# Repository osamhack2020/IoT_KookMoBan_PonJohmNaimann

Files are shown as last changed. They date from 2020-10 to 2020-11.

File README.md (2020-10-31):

# 국방모바일반납 (Pon Johm Naimann-IoT 파트)





## Introduction
<p align="center">
GitHub contributors
</p>

**국방모바일보안**은 병사와 통제간부 모두가 만족하며 사용할 수 있는, **일방적인 금지와 통제**로 이루어지지 않는 스마트폰 반납 시스템을 개발하기 위한 프로젝트입니다. IoT, APP, WEB 분야의 기술을 함께 사용합니다.

## Manual
본 프로젝트는 오픈소스 프로젝트로 진행되며, 본 프로젝트에 관심이 있는 개발자와 사용자를 위하여 **튜토리얼 GitBook**을 제작하여 공개하고 있습니다.

<p align="center">
<a href="https://kookmoban.gitbook.io/osam/">

</a>
</p>

## Contribution
금년도 오픈소스아카데미 집체교육이 **비대면**으로 이루어짐에 따라, 모든 프로젝트는 **서로 얼굴도 알지 못하는 상태**에서 진행됩니다. 따라서 소통은 실시간 소통이 가능하고 문서화에 유리한 아래의 **Notion 페이지**에서 이루어집니다.

<p align="center">
<a href="https://www.notion.so/OSAM-265735b9b76b4bccbff7ce2c4739acd9"  target="_blank">

</a>
</p>

## License
라이센스의 구체적인 내용 및 써드파티 SW에 대해서는 본 리포지토리의 LICENSE 파일 및 튜토리얼 GitBook의 <a href="https://kookmoban.gitbook.io/osam/license/iot-license">LICENSE 페이지</a>를 참조하십시오.
* IoT
  * Code for Arduino: GPL v3
  * Code for RaspberryPi: BSD 3-Clause
* APP: BSD 3-Clause
* WEB: BSD 3-Clause

## Copyright
Copyrightⓒ 2020 Pon Johm Naimann, All rights reserved.

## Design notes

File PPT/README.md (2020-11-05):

# PPT
* [발표자료 (PDF)](https://github.com/osamhack2020/IoT_KookMoBan_PonJohmNaimann/blob/master/PPT/showdown.pdf)
* [발표자료 (PPTX)](https://github.com/osamhack2020/IoT_KookMoBan_PonJohmNaimann/blob/master/PPT/showdown.pptx)
* [발표자료 (PPSX)](https://github.com/osamhack2020/IoT_KookMoBan_PonJohmNaimann/blob/master/PPT/showdown.ppsx)
* [대본](https://github.com/osamhack2020/IoT_KookMoBan_PonJohmNaimann/blob/master/PPT/script.docx)

# 시연 영상
* [종합시연영상](https://youtu.be/DbWCQ2gI8T8)
* [기기등록영상](https://youtu.be/X1ljW4mC4LE)
* [기기반납영상](https://youtu.be/j-UtmO9tqu4)
* [TOTP시연영상](https://youtu.be/JxOJ6xShL1s)

> 시연영상이 전부 100MB을 넘겨서 직접 첨부가 불가능합니다ㅠㅠ 링크를 참조해주세요!  
> Every performance video exceeds 100MB, so Github rejects to upload these files :( Plz check links above.

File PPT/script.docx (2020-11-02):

안녕하세요, 스마트폰 비대면 반납 시스템을 주제로 ‘국방모바일반납‘ 프로젝트를 진행한 ‘폰 좀 내이만’ 팀입니다. 저희 발표는 다음과 같은 순서로 진행되겠습니다.

혹시 여러분은 이 앱을 아시나요? (청중의 반응을 잠시 듣는다.) 아무래도 군과 관련된 분들은 알고 계신 눈치이고, 그렇지 않은 분들은 잘 모르는 눈치네요. 이 ‘국방모바일보안’이라는 앱은, 군부대 내부에서 카메라 사용을 제한하기 위해 병사들의 스마트폰에 설치하도록 되어있는 앱입니다. 이 앱을 깔면 그 핸드폰에서는 카메라와 관련된 기능에 전혀 접근할 수 없게 됩니다. 카메라를 사용하려고 하면 앱을 강제로 종료하는 식으로 말이죠. 사소한 정보 하나하나가 보안과 직결되는 군에서 꼭 필요한 기능이라고 할 수 있겠죠?

하지만, 이 앱에 대한 평가는 그리 좋지 않습니다. 우선 휴가를 나와서 카메라 제한을 해제했는데도 카메라가 켜지지 않거나, 앱을 설치한 뒤 성능이 저하되고 발열이 심해지거나, 카메라 기능과는 무관한 어플을 강제 종료하는 실질적인 문제가 있습니다. 그리고 앱을 임의로 삭제하는 것을 방지하기 위해 ‘모든 데이터 삭제’ 권한을 요구하는데, 일반 사용자가 보면 걱정부터 들죠. 게다가 아이폰 최신 기종의 경우, 이 어플이 작동하지 않습니다. 이런 불편과 불안을 저희가 직접 경험하고 있던 중에…

이번 온라인 해커톤의 지정과제가 발표되었습니다. 그리고 저희는 이 주제에 주목했는데요, 바로 ‘생활관 병사 스마트폰 비대면 반납 앱’입니다. 저희는 걱정이 들었습니다. 제 2의 ‘국방모바일보안’을 염두에 두고 있는 것은 아닌지 말이죠. 정말 앱을 통해서만 사용자의 동작을 감지하고, 강제성을 동원해서 통제해야만 하는 것인지 생각하던 중에, 어? 이거 IoT를 같이 사용하면 잘 해결할 수 있을 것 같은데? 하고 생각하게 되었습니다.

그래서 저희는 비대면 반납 ‘시스템’을 만들기로 했습니다. 그리고 몇 가지 조건을 걸었어요. 첫째로, 모든 반납과 불출 과정, 반납 현황을 확인하고, 실물을 확인하는 과정까지도 비대면이어야 합니다. 둘째로, 앱에서 많은 권한을 요구해서 스마트폰의 성능과 기능에 영향을 끼치면 안됩니다. 셋째로, 비정상 반납 행위로부터 충분한 방어력을 갖추어야 합니다. 몰래 반입한 스마트폰을 대신 제출하는 등의 행위로부터 말이죠. 마지막으로, 스마트폰의 기종에 무관하게 시스템이 적용될 수 있어야 합니다.

이 조건을 바탕으로 수많은 시스템을 고민하고 검증해보았습니다. 시나리오를 작성하고, 파훼법이 있는지 확인하고, 다시 고민하고. 그 결과 이런 와이어프레임을 만들 수 있었어요. 서버가 난수를 전송하고, 앱에서 QR코드를 띄우고, 이걸 반납기가 읽어서 검증하고. 추가적으로 무게도 재고 사진도 찍어서 기존의 기록과 비교하도록 하면 완벽하겠죠.

하지만 몇 가지 문제가 있었습니다. 첫째로, 사용자가 QR코드를 베끼면 어떡하죠? 스크린샷을 찍어서 다른 기기에 전송하고 대신 반납하면? 아니면 모눈종이에 QR코드를 베끼고 쇳덩이에 붙여서 반납하면? 피식 웃으시는 분들이 계신데, 우리 뛰어난 국군 병사들, 이정도는 충분히 해냅니다.

그래서 대책을 세웠습니다. 기기가 반납기에 들어가고 문이 잠긴 뒤에 앱에 난수를 알려주는 겁니다. 음, 괜찮은 것 같아요.

하지만 또 문제가 생깁니다. 몇몇 부대나 파견지는 네트워크 상황이 좋지 않은 경우도 있거든요. 그래서 또 고민과 조사를 계속한 끝에, TOTP기술을 사용하기로 했습니다. 앱을 초기 등록할 때에만 서버와 통신하여 UUID를 정하고 이후 반납시에는 UUID를 SEED로 하여 TOTP를 생성하는 방식인거죠. 그리고 TOTP생성의 간격을 10초로 두고, 반납기가 기기 진입 후 10초를 기다리게 하면 사용자가 접근하지 못한 깨끗한 QR코드를 인식할 수 있게 됩니다.

이러한 발전 과정을 통해 처음의 시스템은 이렇게 바뀌었습니다. 이 시스템은 반납 과정도 비대면이고, 반납 정보도 서버가 다 저장하고 있으므로 현황 확인도 비대면으로 할 수 있습니다. 게다가 앱에서 요구하는 권한은 일절 없으면서, 기종과 무관하게 구현 가능합니다. 핵심적인 인증 방법인 TOTP 생성은 초기 등록시에 앱과 서버가 공유하는 난수를 필요로 하므로 등록 기기에서만 반납이 이루어질 수 있습니다. 따라서 비정상 반납도 크게 방지됩니다.

저희가 처음 설정한 네 가지 조건이 전부 달성되었네요.

이제 이론은 완벽한데, 실제로도 이 시스템이 돌아갈 수 있을까요? 네! 가능합니다. 저희가 앱도 제작하고, 현황 관리 서버와 웹페이지도 제작하고, 반납기도 오픈소스 하드웨어로 설계해서 실제로 제작한 다음 이 시스템이 정말 작동하는지 확인해 보았습니다.

(시연영상)

이런 시스템이 있다면 당연히 스마트폰 사용 시간 준수와 도난 방지에 큰 도움이 될 것이고, 미등록 기기 등을 사용한 비정상 반납도 방지하면서, 미등록 기기를 적발하는데도 사용될 수 있습니다. 무엇보다도 모든 과정이 비대면이므로, 휴가 복귀 후 격리자들에게 적용했을 때 특히 큰 효과를 볼 것입니다. 어쩔 수 없이 격리자들에게 24시간 핸드폰을 허용할 수밖에 없는 현재 상황에 큰 개선이 있겠지요. 그리고 이 모든 효과를 사용자들에게 부담을 지우지 않으면서 얻을 수 있습니다.

이렇게 반납 시스템에 대한 핵심 개념을 모두 완성하고 검증까지 마쳤지만, 저희는 이 프로젝트에서 큰 발전가능성을 느꼈습니다. 이 시스템을 더욱 발전시킬 수 있는 여러가지 방안들이 계속해서 떠올랐기 때문입니다.

첫째로, QR코드 색상암호화 방식을 개발했습니다. 이런 일반적인 QR코드는 아무나 해독해서 그 안에 든 내용을 확인할 수 있습니다. 그런데, 이게 뭘까요? 일반적인 QR코드 인식기처럼 흑백으로 만들어볼까요? 음, 그래도 모르겠네요. 그럼 이건 어떨까요?

네, 이 이미지는 QR코드의 흰 블록과 검은 블록마다 빨강, Red의 강도를 다르게 준 이미지입니다. 나머지 Green과 Blue의 강도는 랜덤하게 부여하고요. 이런 이미지를 기기에 띄우고, 이미지에서 Red의 값만 따오게 되면 QR코드의 형태가 명확하게 보입니다.

당연하지만 같은 원리를 사용하면 빨강이 아닌 그 어떤 색도 Key Color로 사용할 수 있습니다. 그리고 ‘색’하나가 아니라, R3 벡터공간을 이루는 임의의 기저로도 암호화할 수 있도록 개발했습니다. 시간에 따라 무작위로 기저를 생성하고, 생성하는 방법을 앱과 반납기에서 동일하게 사용하면 검증 단계가 훨씬 안전해질 것입니다.

둘째로, 관리자용 앱에 대한 아이디어입니다. 병사 기기와 통신하기 위해서는 서버가 반드시 국방망 외부에 존재해야 합니다. 하지만 보통 부대 내에 일반PC는 사이버지식정보방밖에 없습니다. 따라서 관리 간부가 서버에 접속하여 현황 확인 및 관리를 하기 위해서는 관리 간부의 스마트폰을 사용할 수 있도록 하여야 합니다. 이에 저희는 관리자용 앱에 필요한 기능을 정리하고, 간단한 와이어프레임을 제작해두었습니다.

셋째로, 반납기에 아두이노를 사용하지 않는 방법입니다. 사실 반납기 제작에 아두이노를 사용한 이유는 단 한가지입니다. 휴가 복귀 전에 제작하려다 보니, 당장 있는 부품을 사용하게 된 것 뿐입니다. 아두이노의 역할은 무게 센서의 값을 AnalogRead하는 것뿐이므로, ADC 컨버터 칩을 사용하면 비용적인 측면에서도 이득이 있고, 소스 공개 의무화를 전염시키는 아두이노의 GPL 라이선스로부터 자유로워질 수 있다는 장점이 있습니다.

마지막으로, 1:N 반납기입니다. 현재 제작한 반납기는 보관함 하나가 기기 하나를 보관하는 방식입니다. 이 보관함을 전군에 보급한다고 하면, 반납기 실물을 제작하는 데 약 8만원이 들었고 국군 병사의 수인 36만개의 반납기를 제작해야 합니다. 단순 계산으로는 288억의 예산이 필요하네요. 하지만 이는 현실적이지 않죠. 그래서 반납기 하나가 여러 대의 기기를 보관할 수 있는 방법을 고안해보았습니다. 기기 검증이 끝난 기기는 공통 보관함으로 이동시키거나, 우편함 형태의 보관함으로 밀어 넣어 보관하는 방식, 기기가 고정된 후 바코드를 찍어 기기를 인증하는 방식 등이 있습니다. 보통 한 생활관을 8명이 사용하므로 8개 단위로 반납기를 제작한다면, 36억의 예산이 필요하겠네요. 이는 시제품에 대한 비용이므로 실제 생산 단가는 줄어들 것이고, 여기서 앱 개발 비용, 인건비 등이 추가되므로 대략적으로 이 정도 규모의 예산이 필요할 것 같습니다.

이외에도 이 프로젝트를 발전시킬 수 있는 방향은 많습니다. 반납 기록에 담기는 기기의 이미지를 기반으로 머신러닝을 돌리면 나중에는 QR코드나 별도 앱 없이, 이미지 인식만으로도 정상 반납 여부를 판단할 수 있을지도 모릅니다. 또한, 서버의 반납 기록 데이터를 통계 및 그래프로 가공하여 관리 간부의 반납 통제에 도움을 줄 수도 있습니다. 이 모든 아이디어들은 해커톤의 시간과 여건상 제안하는 데 그쳤지만, 만약 이것이 일반적인 오픈소스 프로젝트였다면 어땠을까요? 창의적이고 능력있는 인재들의 관심 속에서 저희가 제시한 방향 뿐 아니라, 수많은 방향으로 발전에 발전을 거듭했을 것입니다.

이렇게 저희 프로젝트에 대한 소개가 끝났습니다. 혹시 관심이 있으시다면, 저희 프로젝트의 깃북을 참조해보시는 것을 추천드립니다. 프로젝트의 협업 방식부터 매뉴얼, 빌드 방법까지 모든 정보를 정리해 두었습니다.

이상으로 발표를 마치겠습니다. 감사합니다.

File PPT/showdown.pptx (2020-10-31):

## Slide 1

폰 좀 내이만 (Pon Johm Naimann)
병장 박찬정
병장 강동민
병장 이진휘

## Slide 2

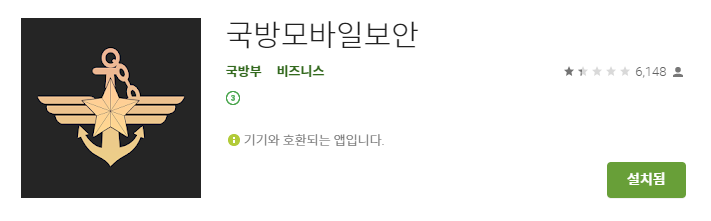
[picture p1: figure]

이 앱을 아시나요?

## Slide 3

“해제했는데도 카메라가 켜지지 않아요.”

많은 불편과 불안

“앱을 설치하니 핸드폰이 느려졌어요.”

“유*브는 왜 강제종료시키죠?”

그러던 중…

“이 권한은 왜 요구하죠?
제 핸드폰을 어떻게 하려는 건가요?”

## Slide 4

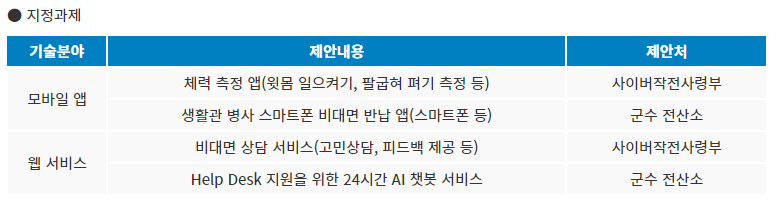
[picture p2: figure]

제 2의 ‘국방모바일보안’이 탄생하는게 아닌지

정말 앱만으로 반납을 통제해야 하는지

IoT로도… 될 것 같은데?!

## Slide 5

비대면 반납 ‘시스템’을 만들자!

💡 비대면으로 이루어져야 함

💡 앱에서 많은 걸 요구하면 안됨

💡 비정상 반납 행위로부터
충분한 방어력을 갖춰야 함

💡 기종에 무관하게 적용할 수 있어야 함

## 이를 만족시킬 수 있는 시스템..?

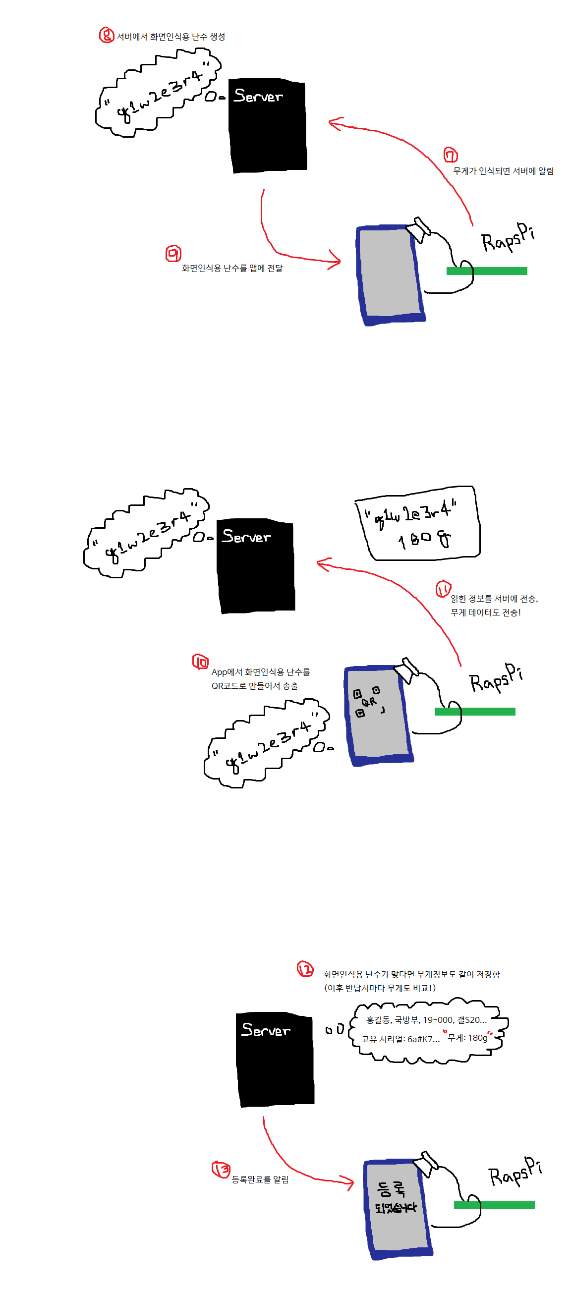
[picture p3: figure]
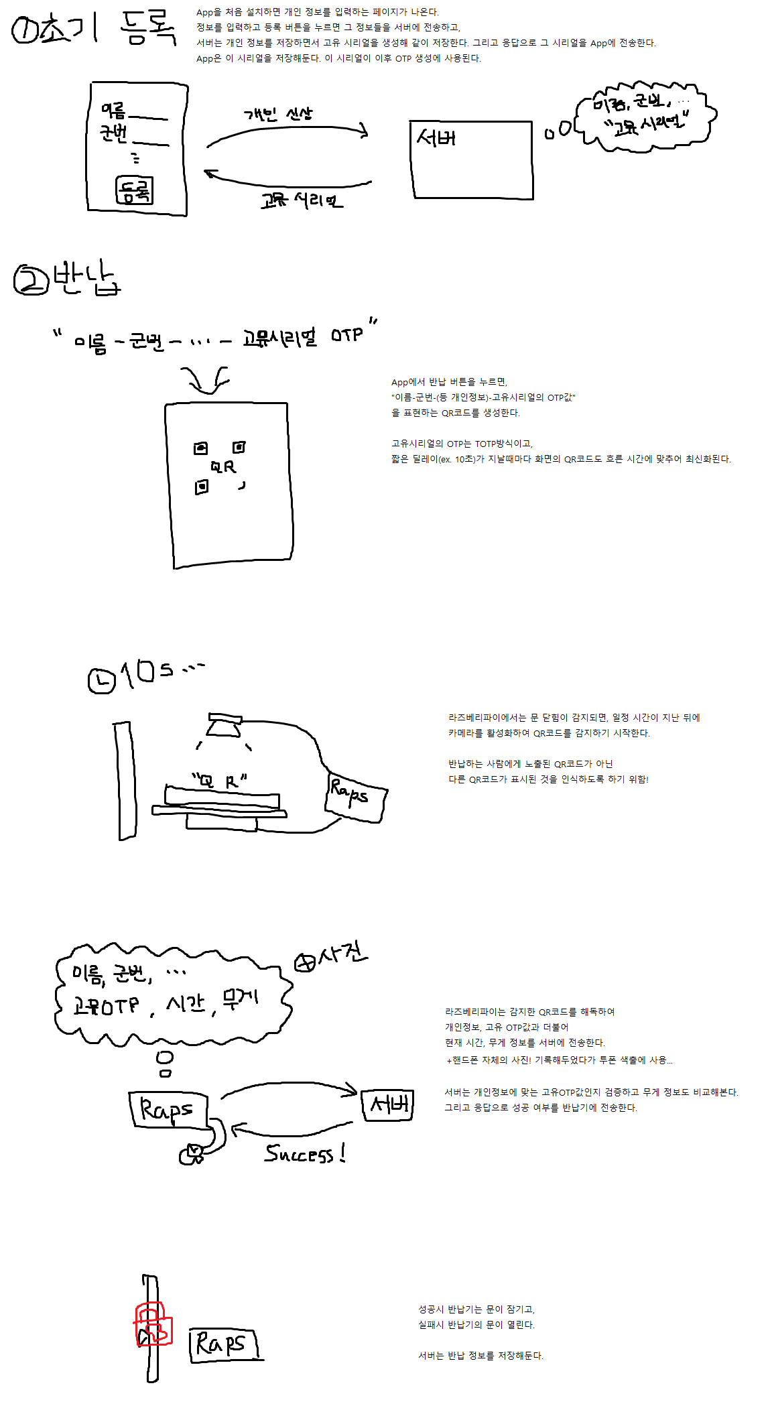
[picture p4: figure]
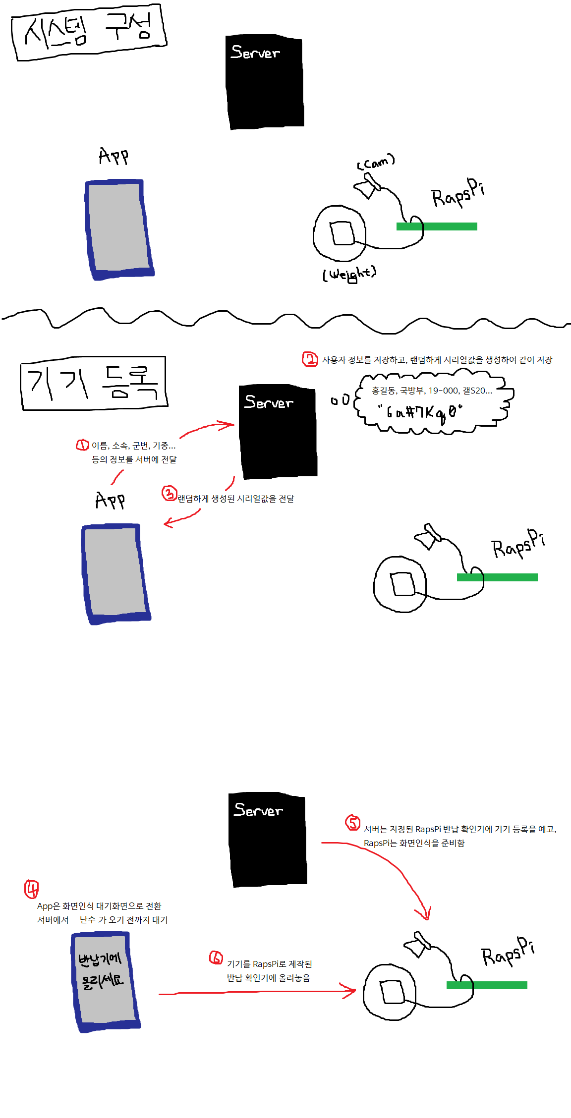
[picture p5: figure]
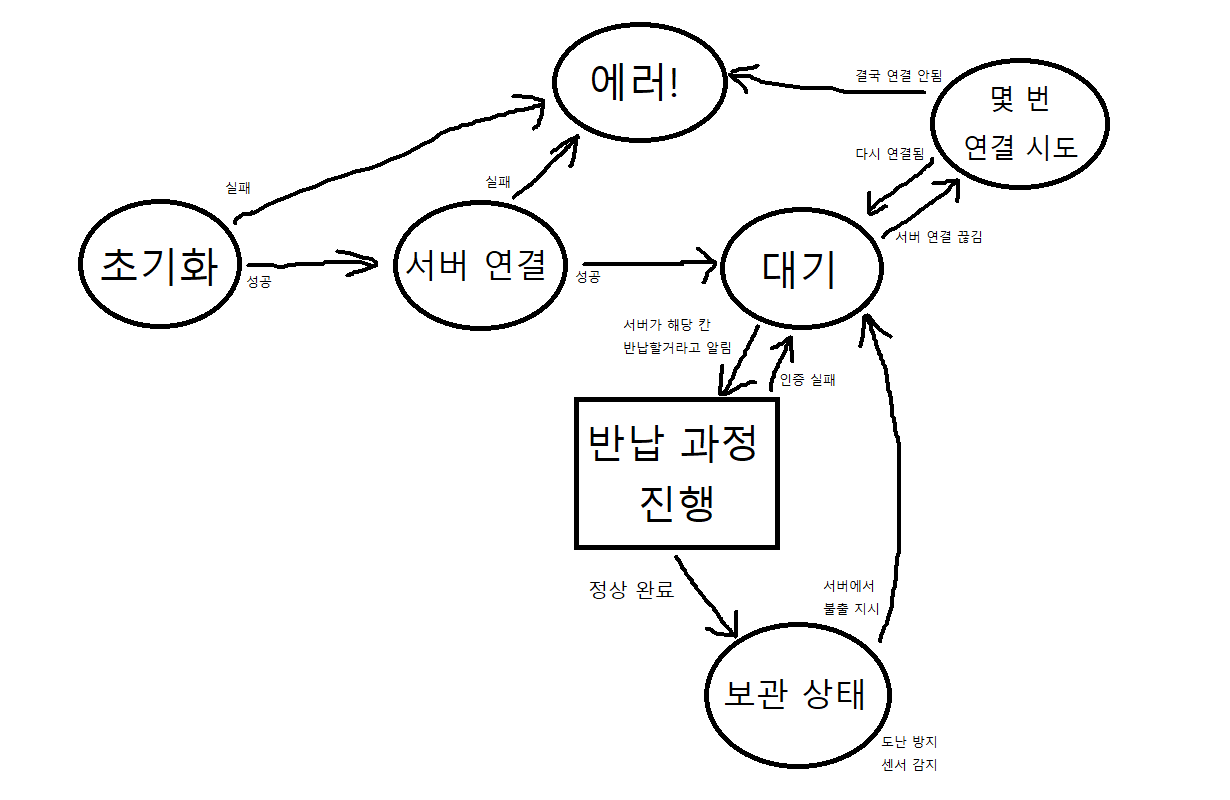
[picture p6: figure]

수많은 시나리오 작성 & 시행착오

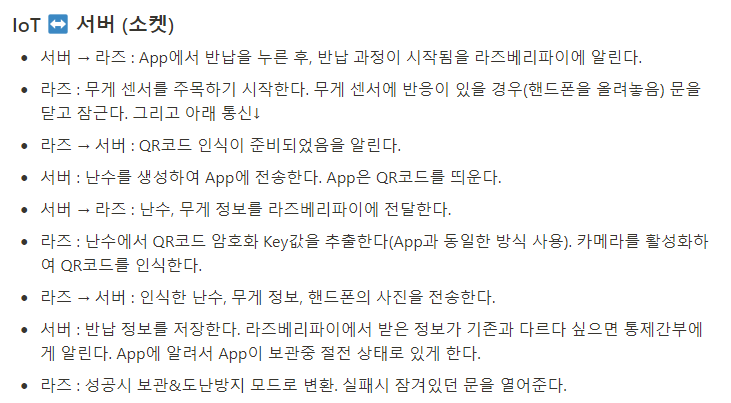
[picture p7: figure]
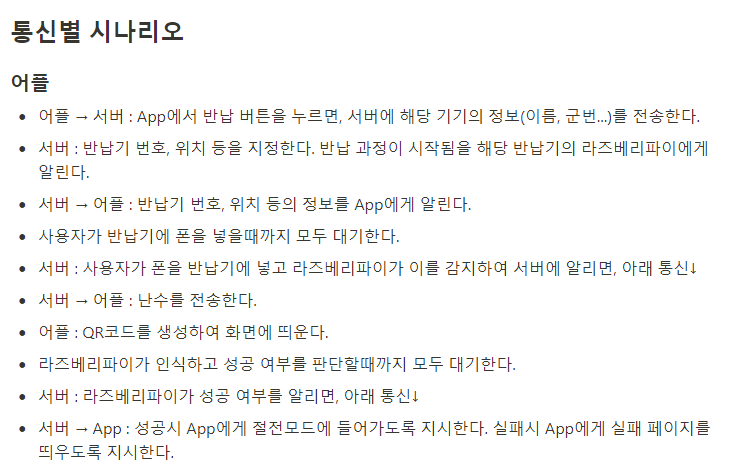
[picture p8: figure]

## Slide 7

Q. QR코드를 사용하자.

A. QR코드를 베끼면? (스크린샷, 모눈종이)

기기가 반납기에 들어간 후에

앱에 난수를 전송하자!

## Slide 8

Q. 그런데 네트워크 연결이 제한될 때는?
(파견지 등)

그럼 TOTP를 사용하자!

그리고 등록시에만 서버로부터 UUID를
발급받아 SEED값으로 사용하자.

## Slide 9

그래서 나온 시스템

## 초기등록

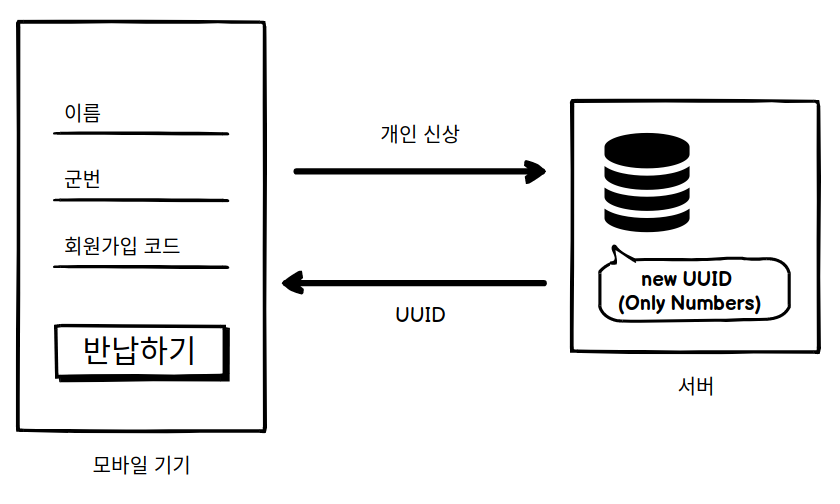
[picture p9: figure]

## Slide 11

앱에서 요구하는 권한

없음

## 반 납

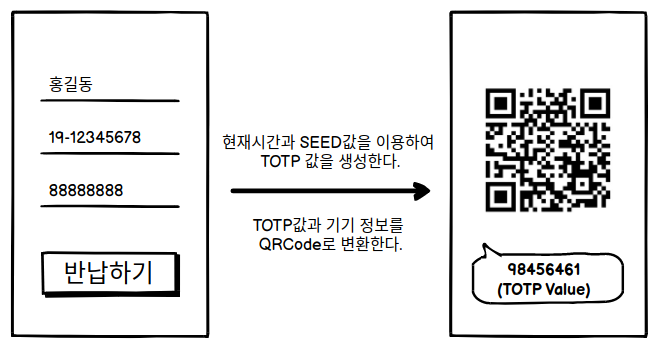
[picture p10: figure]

## 반 납

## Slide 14

반납 - TOTP 검증

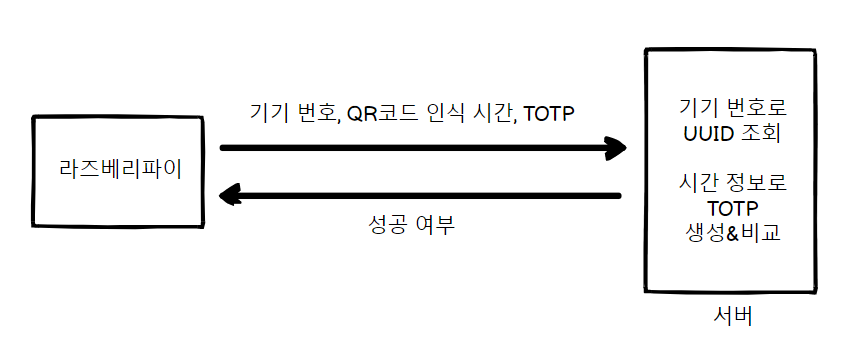
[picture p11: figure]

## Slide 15

반납 성공 - 반납기록 전송

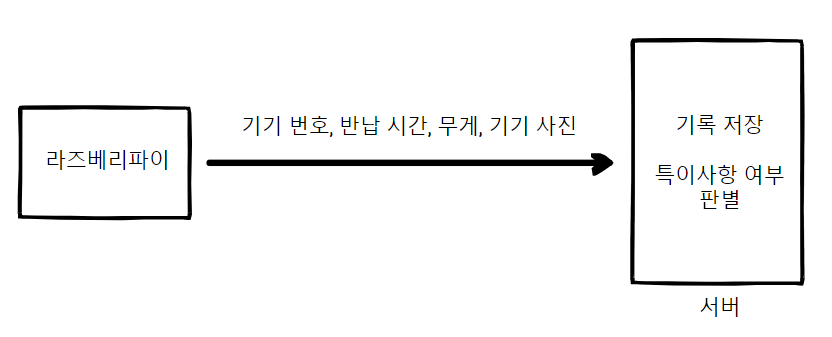
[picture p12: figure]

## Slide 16

반납 실패 - 다시 시도하도록 안내

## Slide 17

시연 영상

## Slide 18

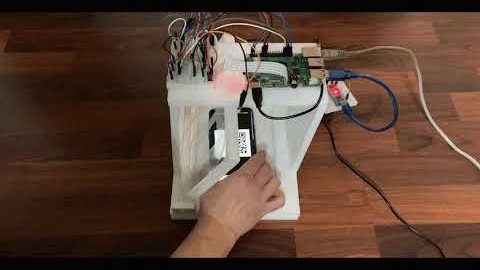
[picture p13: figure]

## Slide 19

고급 기능

## QR코드 색상암호화

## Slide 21

아무나 해독 가능

일반 QR코드

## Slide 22

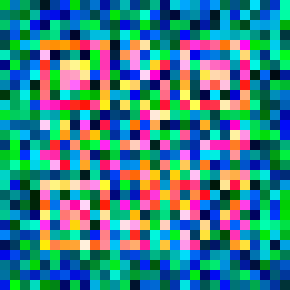
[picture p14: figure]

붉은색 선글라스를 끼면 QR코드의 형태가 명확해진다!

???

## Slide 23

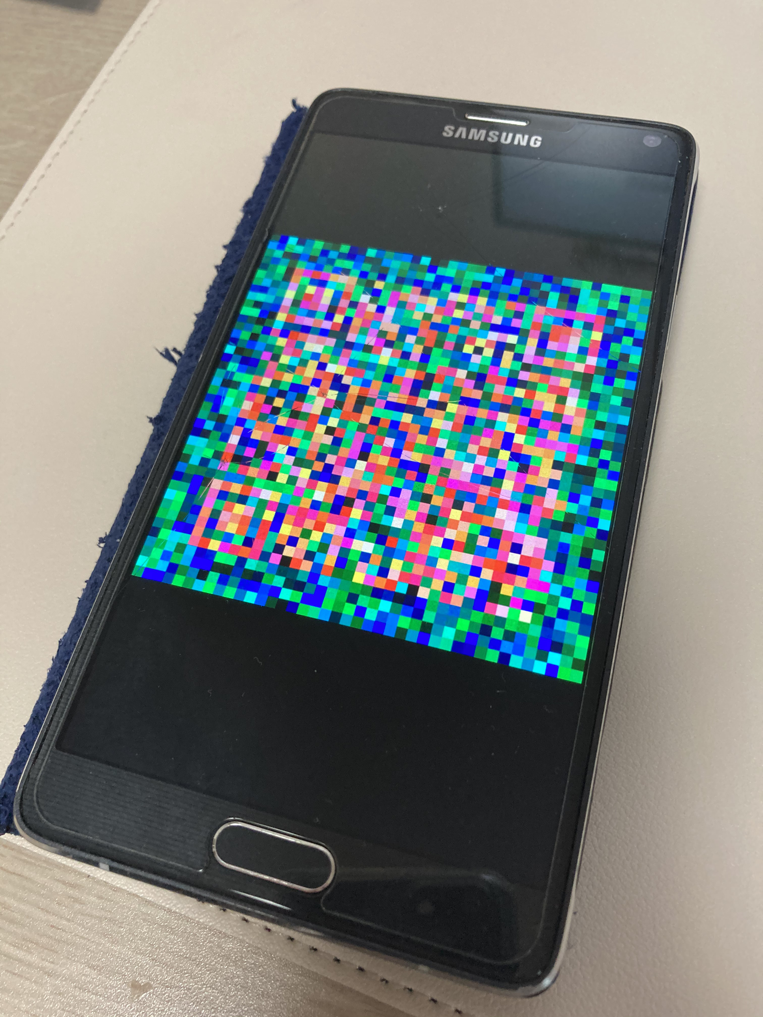
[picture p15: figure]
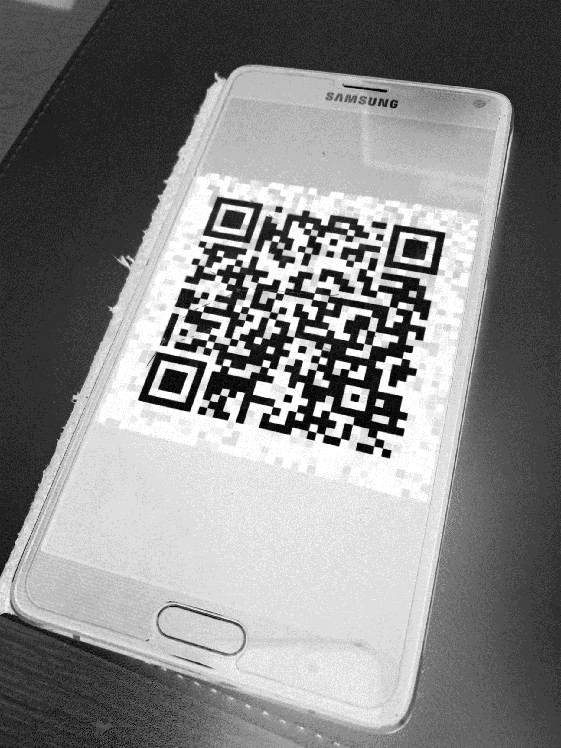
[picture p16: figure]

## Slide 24

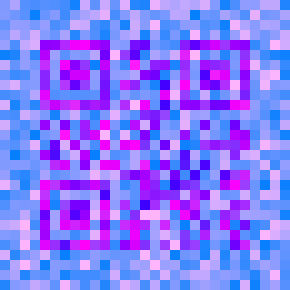
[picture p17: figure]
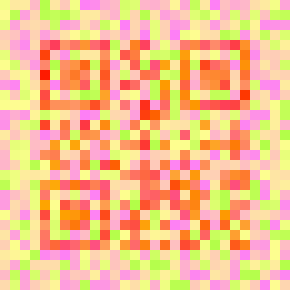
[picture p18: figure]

모든 색으로
암호화 가능

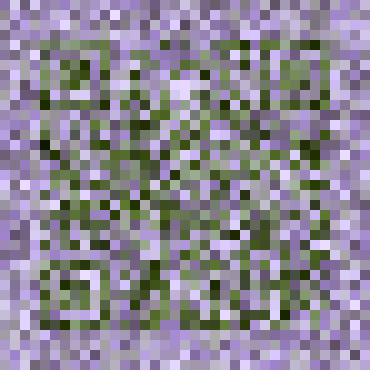
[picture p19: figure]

‘색’이 아닌
임의의 세 벡터로도 가능

## 관리자용 앱

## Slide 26

📟
서버는 반드시 국방망 외부에 있어야 함.
(병사 기기와 통신 불가)

🖥
부대 내 일반PC는 사지방밖에 없음.
(사용성이 매우 떨어짐)

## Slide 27

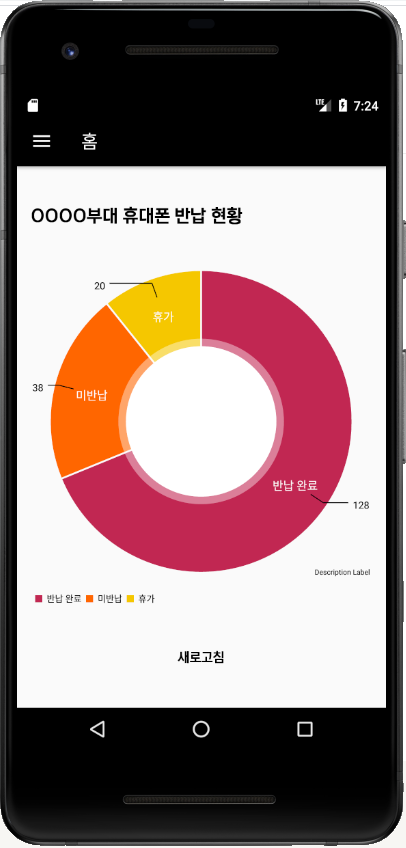
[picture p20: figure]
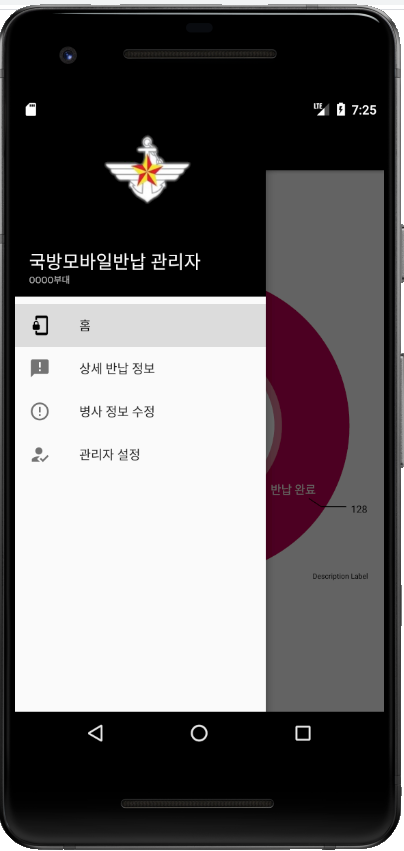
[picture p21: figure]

📱
따라서 관리 간부의 스마트폰을 통해
서버에 접속하고 현황을 관리하여야 함.

## 아두이노 미사용

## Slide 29

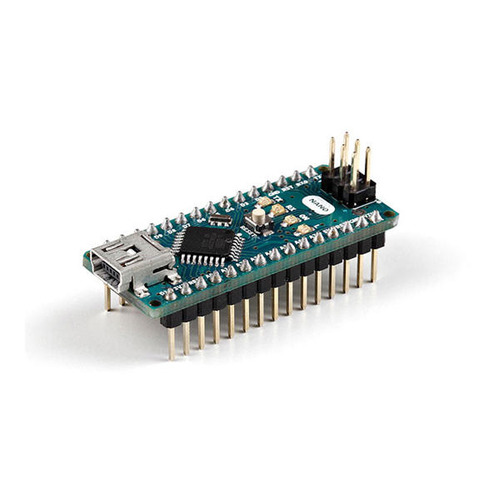
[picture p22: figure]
아두이노 나노 정품 (Arduino Nano)

아두이노의 GPL 라이선스로부터도
자유로워질 수 있음

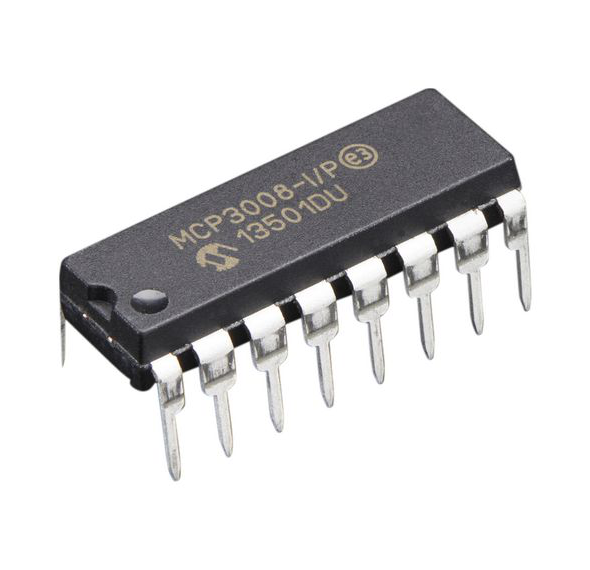
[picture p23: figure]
856 MCP3008 8-Channel 10-Bit ADC with SPI Interface Adafruit

## 1:N 반납기

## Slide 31

기기 N대 : 반납기 1대

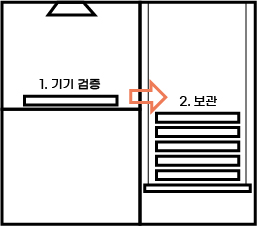
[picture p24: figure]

기기 1대 : 반납기 1대

## 📃 자세한 내용은 깃북 참조 부탁드립니다!

## 감사합니다.

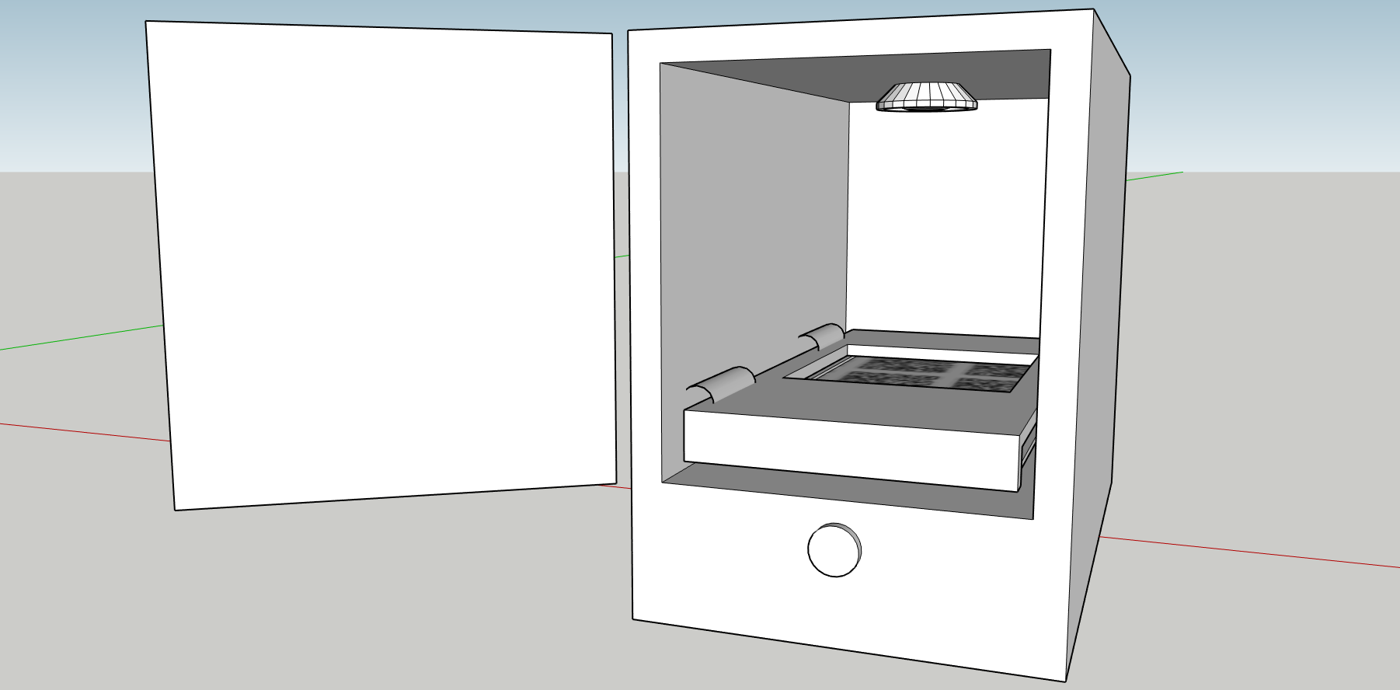
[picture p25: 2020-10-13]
doc/iot_docu/concept_photo/concept03.png

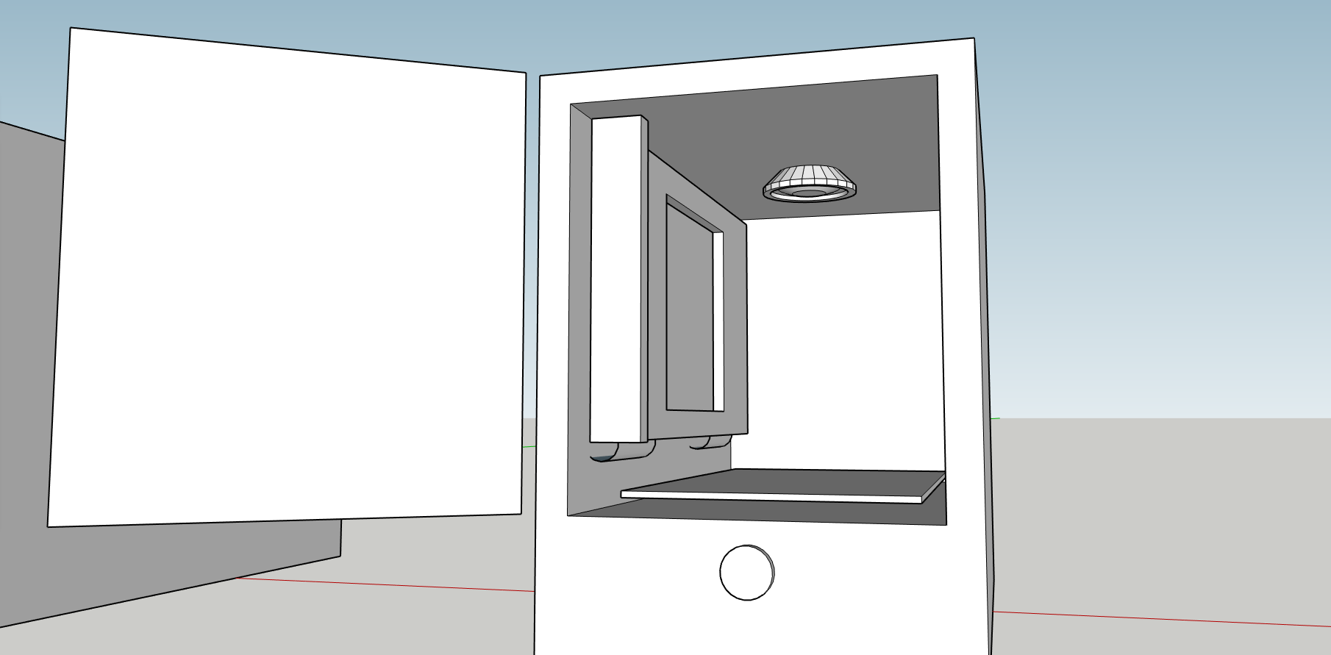
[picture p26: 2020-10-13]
doc/iot_docu/concept_photo/concept01.png

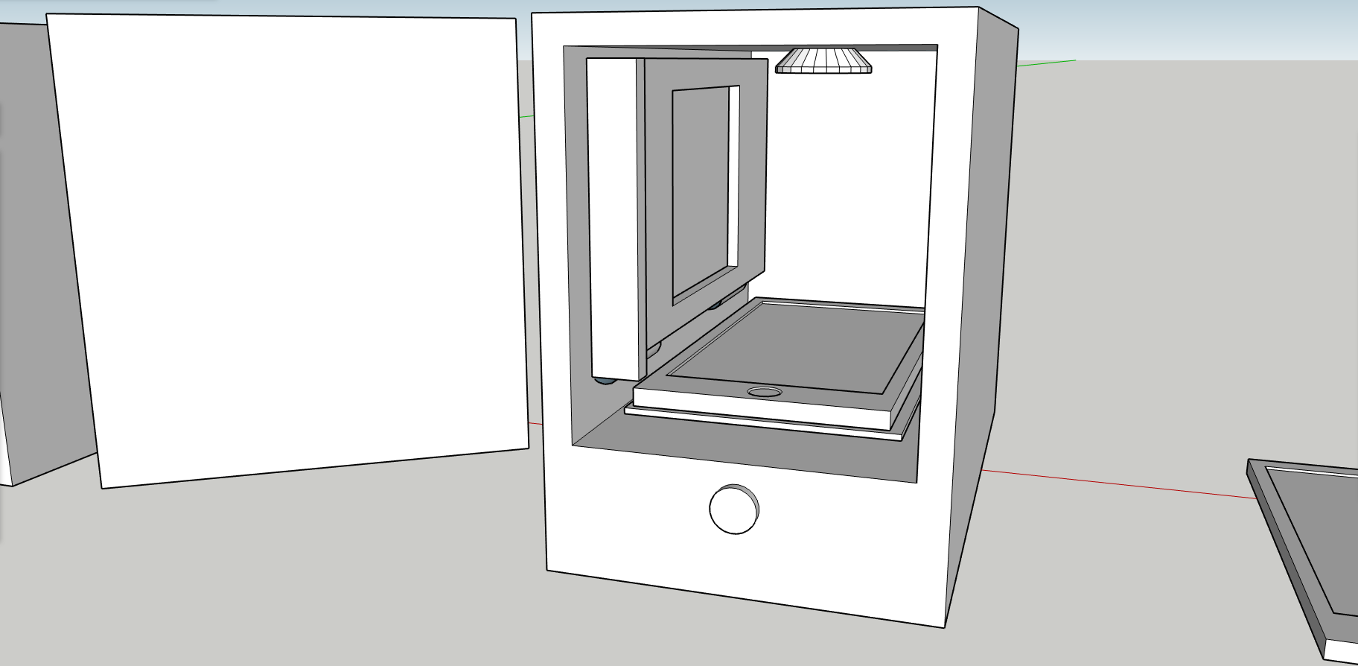
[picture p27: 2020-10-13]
doc/iot_docu/concept_photo/concept02.png

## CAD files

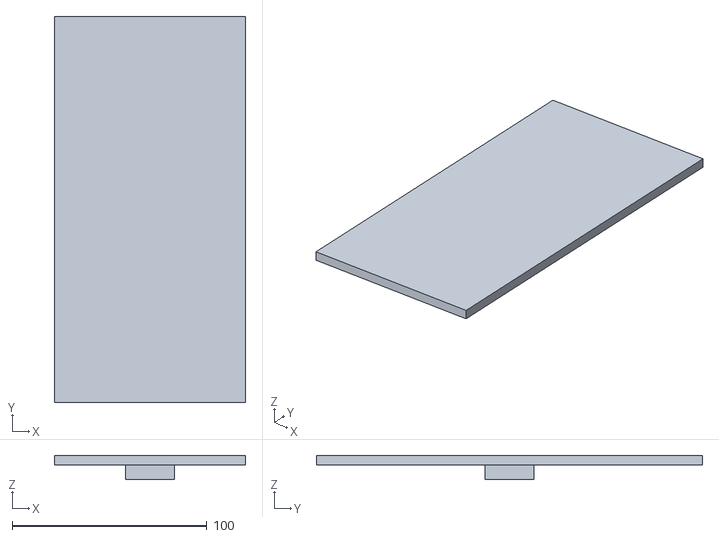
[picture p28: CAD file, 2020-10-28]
doc/iot_docu/3d_model/Receiver - Part 3.stl
98.0 x 198.0 x 12.5

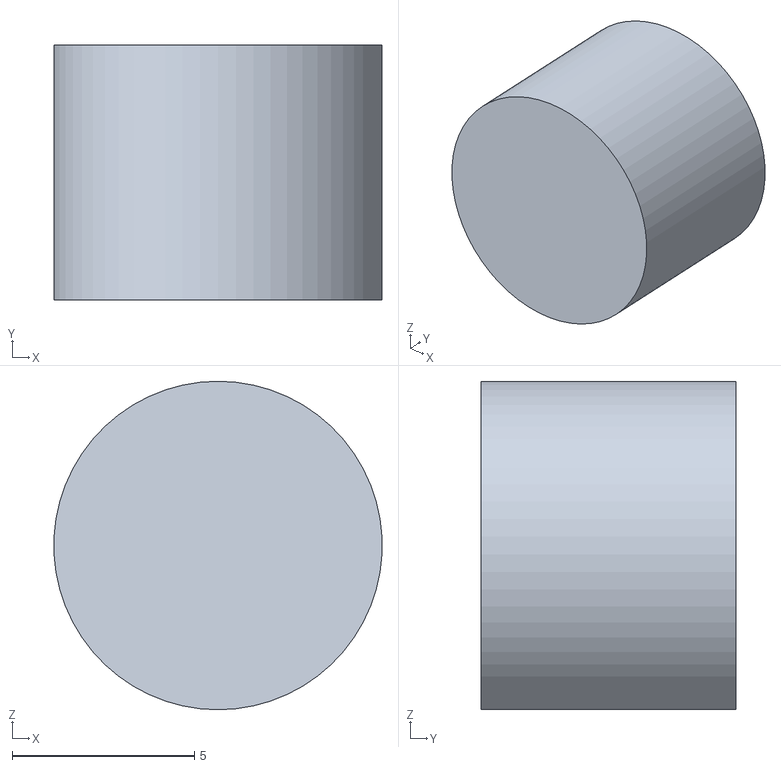
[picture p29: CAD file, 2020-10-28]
doc/iot_docu/3d_model/Receiver - Part 6.stl
8.99 x 7.00 x 9.00

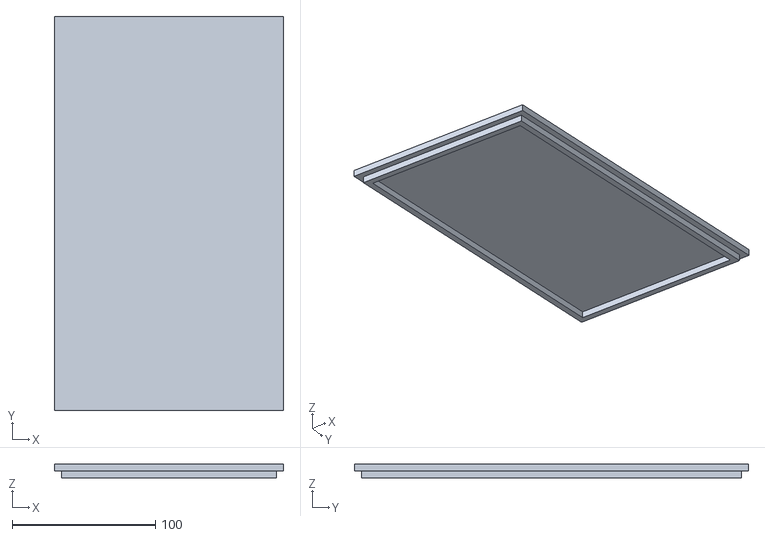
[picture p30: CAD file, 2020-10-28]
doc/iot_docu/3d_model/Receiver - Part 5.stl
160.0 x 275.0 x 10.0

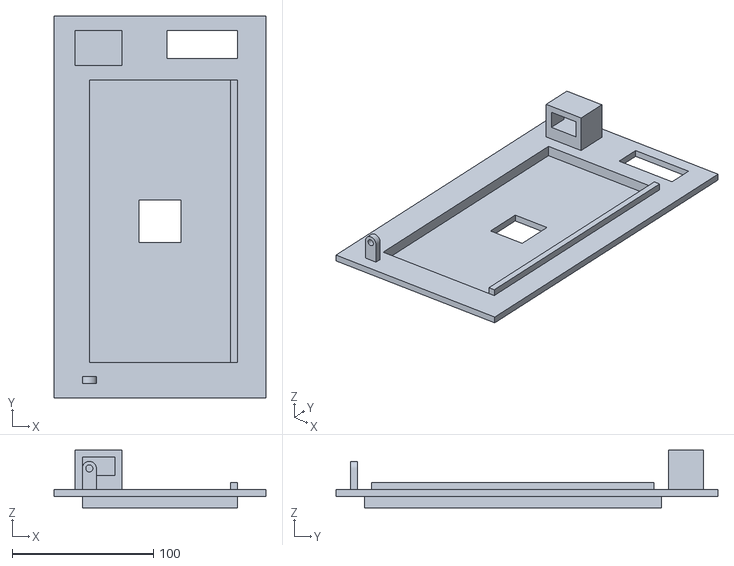
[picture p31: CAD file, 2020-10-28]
doc/iot_docu/3d_model/Receiver - Part 2.stl
150.0 x 270.0 x 41.0

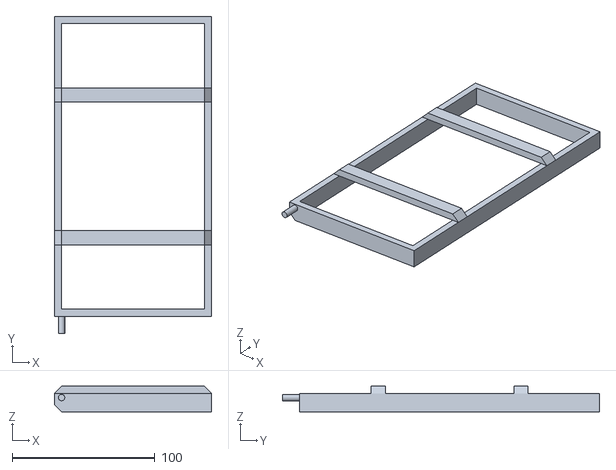
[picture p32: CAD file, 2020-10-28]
doc/iot_docu/3d_model/Receiver - Part 7.stl
110.0 x 222.0 x 18.0

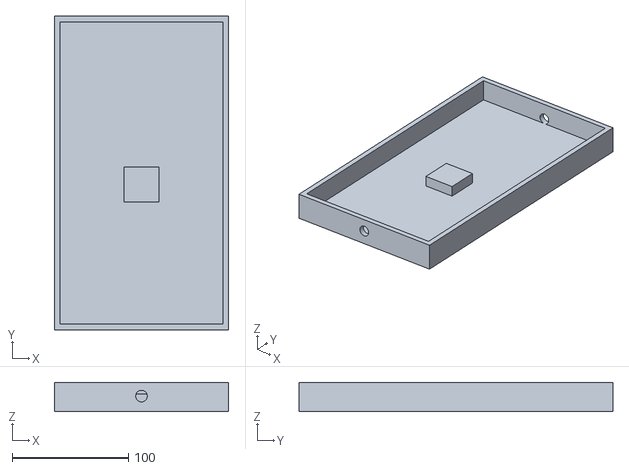
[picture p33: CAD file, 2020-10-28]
doc/iot_docu/3d_model/Receiver - Part 1.stl
150.0 x 270.0 x 25.0

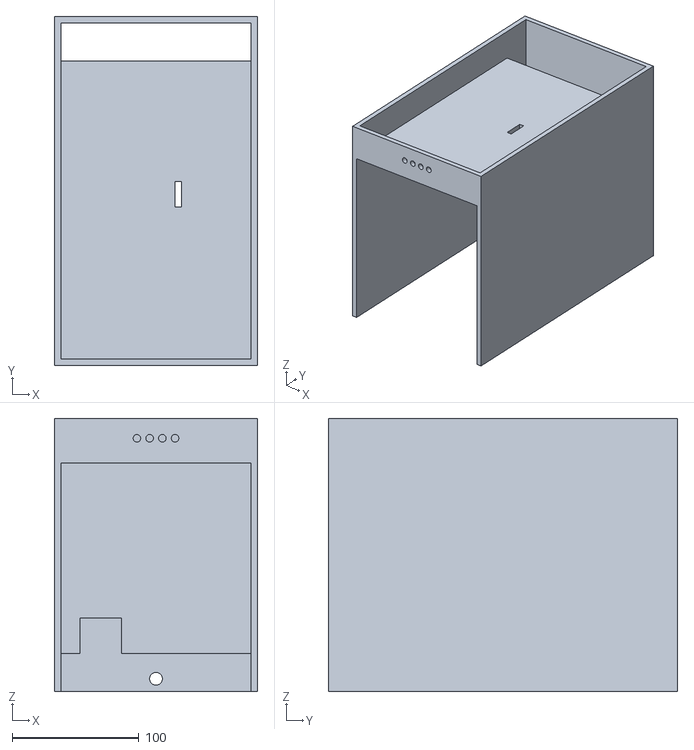
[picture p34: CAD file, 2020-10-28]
doc/iot_docu/3d_model/Receiver - Part 4.stl
160.0 x 275.0 x 215.0

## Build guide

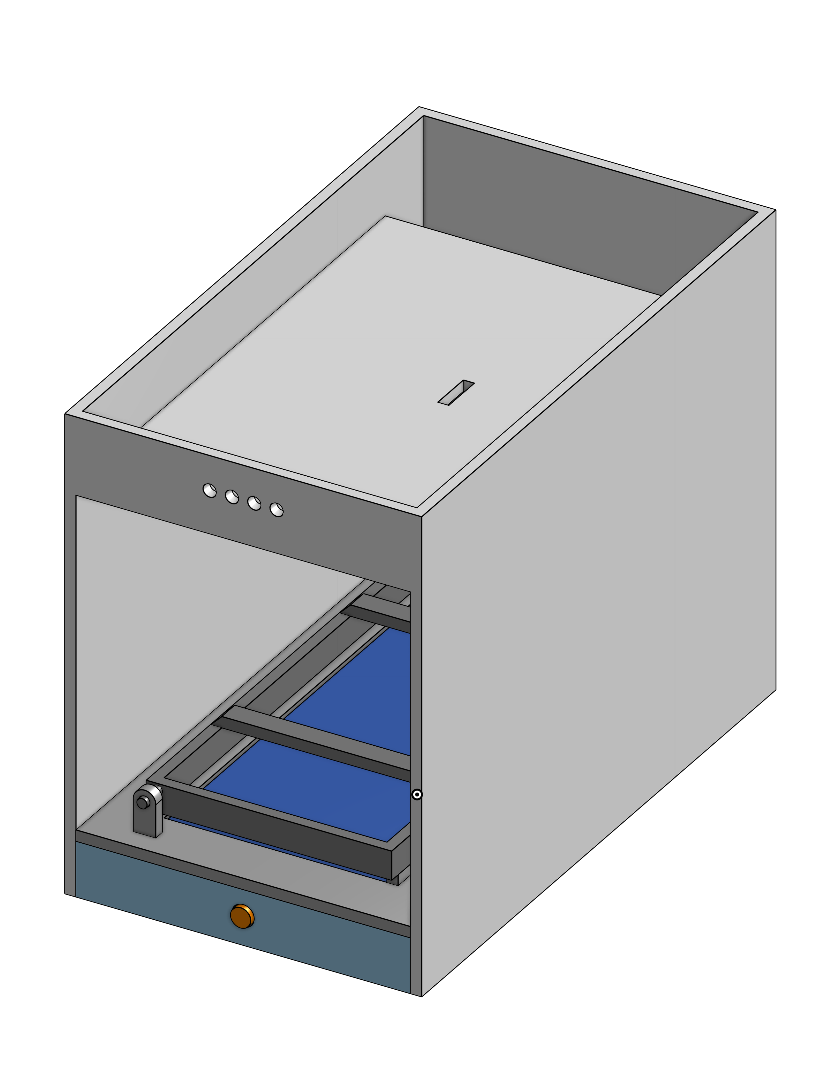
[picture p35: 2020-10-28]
doc/iot_docu/hw_build_guide/05.png

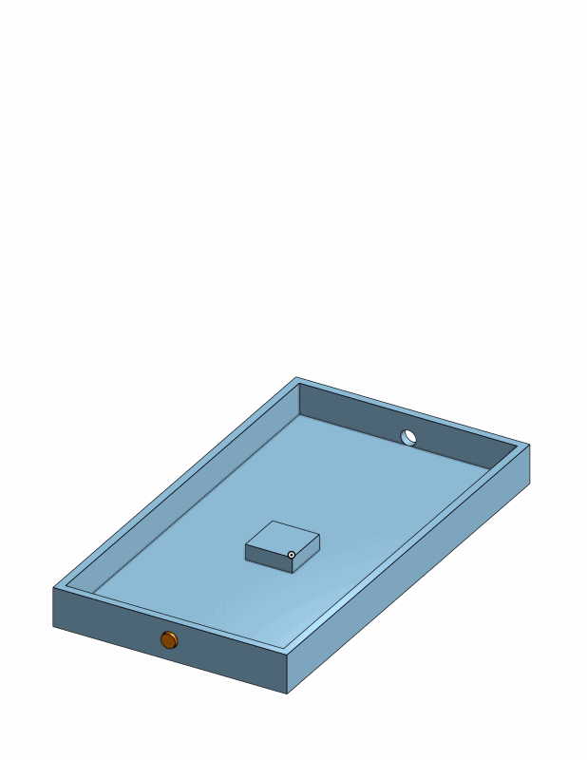
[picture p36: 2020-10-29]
doc/iot_docu/hw_build_guide/whole.gif

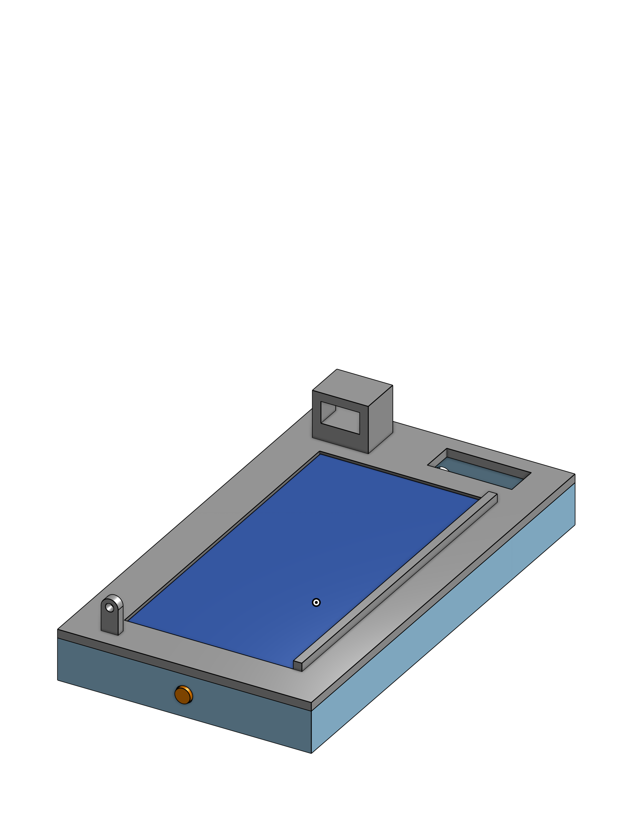
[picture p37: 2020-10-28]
doc/iot_docu/hw_build_guide/03.png

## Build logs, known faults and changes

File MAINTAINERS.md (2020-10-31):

**List of maintainers**

[IoT Repository](https://github.com/osamhack2020/IoT_KookMoBan_PonJohmNaimann)
* ChanJeong Park(@ckswjd99) <ckswjd99@snu.ac.kr>

[APP Repository](https://github.com/osamhack2020/APP_KookMoBanUser_PonJohmNaimann)
* Jinwhuy Lee(@Jinwhuy) <jinwhuy.lee@gmail.com>

[WEB Repository](https://github.com/osamhack2020/WEB_KookMoBan_PonJohmNaimann)
* DongMin Kang(@riyenas0925) <riyenas0925@gmail.com>

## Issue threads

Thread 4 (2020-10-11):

[ENH] QR코드를 인식한 값을 서버에 전송하여 반납 기기를 검증하는 기능 구현

ckswjd99, 2020-10-11:
카메라가 찍는 QR코드를 읽고 아래 항목에 대한 정보를 각각 추출한다.
* 기기ID
* TOTP

그리고 서버에 아래와 같은 JSON 데이터를 POST 방식으로 전송하여 응답으로 성공 여부를 받는다.
{
&nbsp;'timeInMillis': 현재 시간의 ms단위 값,
&nbsp;'deviceId': QR코드에서 읽은 기기의 고유 Id,
&nbsp;'expectedTOTP': QR코드에서 읽은 기기가 생성한 TOTP값
}

Closed 2020-10-11.

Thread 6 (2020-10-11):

[ENH] Key Vector를 기반으로 이미지를 Decoding 하는 기능 구현

ckswjd99, 2020-10-11:
특정 색상으로 암호화된 QR코드를 Decoding 하기 위해, 특정 색상의 RGB값을 Key Vector로 하여 이미지 전체를 변환한다.
변환 과정은 아래와 같다.

1. Key Vector를 기준으로 Gram-Schmidt 과정을 통해 Orthonormal Basis를 생성한다. 이를 Key Basis라 하자.
2. 이미지의 각 Pixel값을 읽고 Key Basis를 Column으로 하여 구성한 행렬의 역행렬과 곱한다.
3. 이 중 Key Vector의 성분에 해당하는 값으로 이미지의 각 Pixel을 대체한다.
4. 이미지 전체를 반전시킨다.

올바른 Key Vector를 통해 위 과정을 진행한다면, 특정 색상으로 암호화된 QR코드 이미지는 선명한 흑백의 QR코드가 된다.

Closed 2020-10-11.

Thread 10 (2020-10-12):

[BUG] phone_autoCut 함수 인자의 type이 통일되지 않음

ckswjd99, 2020-10-12:
코드 전체에서, 사진에서 핸드폰 영역만 잘라주는 함수인 phone_autoCut의 인자로서 주는 것들이 중구난방임.
* str : 테스트를 위해 찍은 핸드폰 사진의 경우, 인자를 str타입의 사진의 경로로 제공함.
* PIL.Image.Image : 화면을 캡쳐하여 사용하는 경우, pillow 라이브러리를 사용하므로 PIL.Image.Image 타입의 객체를 인자로 제공함.
* np.ndarray : 이후 카메라를 사용할 경우, cv2 라이브러리를 사용하므로 numpy.ndarray 타입의 객체를 인자로 제공하게 됨.

따라서 함수를 실행시키면 가장 처음으로 인자의 type을 확인하여 numpy.ndarray형식으로 변환한 뒤 기존의 과정을 수행하도록 하여야 한다.

또한 함수에서 오류가 발생하는 경우, 함수가 False가 아닌 원본 사진에 해당하는 numpy.ndarray를 반환하도록 하는 것이 유리할 것임.

Closed 2020-10-12.

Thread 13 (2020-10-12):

[ENH] 문 잠금, 잠금해제 기능 구현

ckswjd99, 2020-10-12:
문을 잠가야 할 때 문이 제대로 닫혀있는지를 확인하여 제대로 된 잠금이 이루어질 수 있도록 확인한다.

ckswjd99, 2020-10-14:
문은 굳이 잠그지 않되, 핸드폰 커버를 잠글 수 있도록 한다.

커버를 잠그기 전에 확인해야 하는 것
* 무게 센서가 0이 아닌지

잠그기 위한 조건에 문제가 없을 때
* 핸드폰 커버를 자동으로 내린다.
* 잠금장치를 자동으로 작동시킨다.

Closed 2020-10-14.

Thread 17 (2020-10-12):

[ENH] 비정상적인 종료 상황을 대비한 반납기 상태 저장 기능 구현

ckswjd99, 2020-10-12:
반납기의 상태에 대한 몇 가지 정보를 파이썬 내장 모듈인 pickle을 활용하여 외부 파일로 저장하도록 한다.
저장하는 항목은 다음과 같다.

* phone_isFull : 핸드폰 보관 상태인지 여부를 확인한다.
* weight : 현재 측정되는 무게를 저장한다.

저장은 반납시, 불출시에 한 번씩 진행한다.

Closed 2020-10-12.

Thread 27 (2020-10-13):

[BUG] 서버에 반납 기록을 전송할 때 phone_autoCut 함수를 거치지 않는 문제 해결

ckswjd99, 2020-10-13:
서버에 반납 기록을 전송할 때 보내는 사진이 phone_autoCut 함수를 거치지 않고서 서버로 전송됨.

또한 반납 기록을 전송하는 함수인 server_returnLog 함수가 phone_autoCut보다 먼저 정의되어있음.

순서를 정리한 뒤, 사진이 phone_autoCut함수를 거치고 서버에 전달되도록 수정하여야 함.

Closed 2020-10-13.

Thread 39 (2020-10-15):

ENH : QRCode에서 deviceId, adminId, totp 값을 읽어오는 기능

riyenas0925, 2020-10-15:
@ckswjd99 찬정님 서버에서 adminId를 받아야지 나중에 관리자가 정한 휴대폰 사용시간인지를 검증할수 있을것 같아서 QRCode에 adminId정보를 추가해 생성하도록 변경해서 아래 이슈 참고해서 제작해주시면 감사하겠습니다

참고 : https://github.com/osamhack2020/WEB_KookMoBan_PonJohmNaimann/issues/54

Closed 2020-10-16.

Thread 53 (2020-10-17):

[DOC] 반납기 회로도 업데이트 (상태표시 LED 추가)

ckswjd99, 2020-10-17:
반납기의 상태를 간단히 알려줄 수 있는 상태 표시 LED를 회로도에 추가하자.

 - 파랑: 정상 보관중
 - 초록: 보관 절차 정상 진행중
 - 노랑: 보관 절차 진행중 오류 발생. 덮개를 열고 핸드폰을 가져가도록 함.
 - 빨강: 보관중 문제 발생. 관리자에게 알림.

ckswjd99, 2020-10-17:
참 그리고 라즈베리파이-아두이노 통신은 파란색 케이블 사용니깐 그것도 반영해야함

Closed 2020-10-17.

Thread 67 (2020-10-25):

[DOC] 반납기 회로도 상태표시 LED 관련 수정 등

ckswjd99, 2020-10-25:
회로도에 저항 사용에 대해 적어두지 않았음.

상태표시에 사용되는 LED는 정격전압 2.2V, 정격전류 30mA이므로 이에 맞는 회로를 구성하여야 함.

또한 문 닫힘의 확인을 위해 KW-10 스위치를 사용하기로 계획하였으나, 서보모터가 예상보다 확실하게 잘 작동하여서 KW-10 스위치는 사용하지 않아도 괜찮을 것 같음.

Closed 2020-10-25.

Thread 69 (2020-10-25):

[BUG] 상태표시 LED 제어 코드 수정

ckswjd99, 2020-10-25:
상태표시 LED 제어 코드가 엉망이다.

복사 붙여넣기를 대충 해서 BLED만 제어하고 가관이다.

수정하자!

Closed 2020-10-25.

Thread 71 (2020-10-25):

[BUG] APP에서 읽은 QR코드의 JSON key이름 맞추기

ckswjd99, 2020-10-25:
APP에서는 QR코드에 정보를 담을 때, JSON의 key값으로
deviceID, adminID
를 쓴다.
나는 서버에 맞춰서
deviceId, adminId
로 썼었는데 오류가 난다. 내가 중간에 적당히 바꿔서 보내주자.

Closed 2020-10-25.

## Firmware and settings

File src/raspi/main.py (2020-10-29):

# sudo apt-get install libzbar0
# pip install opencv-python

import RPi.GPIO as gp
import picamera
import serial

import numpy as np
import time
import pickle
import json
import copy
import base64

import requests
from pyzbar import pyzbar
from PIL import Image
from PIL import ImageFilter
from PIL import ImageEnhance
import PIL.ImageOps

import cv2


##======================= CONSTANTS =======================##

SERVER_URL      = 'https://osam.riyenas.dev'
SERVER_MAXTRY   = 1
TOTP_DELAY      = 10

PIN_RECVPHONE	= 36
PIN_DOORCLOSE0	= 38
PIN_DOORCLOSE1	= 40
PIN_SERVO0 		= 11
PIN_SERVO1		= 13
PIN_LEDLIGHT	= 16
PIN_BLED		= 37
PIN_GLED		= 35
PIN_YLED		= 33
PIN_RLED		= 31

SERVO_MIN_DUTY	= 3
SERVO_MAX_DUTY	= 12

SERIAL_PORT     = '/dev/ttyUSB0'


##======================= GPIO INIT =======================##

gp.setmode(gp.BOARD)
gp.setup(PIN_RECVPHONE, gp.IN)
gp.setup(PIN_DOORCLOSE0, gp.IN)
gp.setup(PIN_DOORCLOSE1, gp.IN)
gp.setup(PIN_SERVO0, gp.OUT)
gp.setup(PIN_SERVO1, gp.OUT)
gp.setup(PIN_LEDLIGHT, gp.OUT)
gp.setup(PIN_BLED, gp.OUT)
gp.setup(PIN_GLED, gp.OUT)
gp.setup(PIN_YLED, gp.OUT)
gp.setup(PIN_RLED, gp.OUT)

servo0 = gp.PWM(PIN_SERVO0, 50)
servo1 = gp.PWM(PIN_SERVO1, 50)
servo0.start(0)
servo1.start(0)

ser = serial.Serial(SERIAL_PORT, 9600)


##==================== PUBLIC VARIABLES ====================##

server_isConnected = False

phone_isFull    = False

door_isOpen     = True

weight_saved    = 0
weight_err      = 0.05

admin_id        = 0

led_status		= 'OFF'		# 'BLUE', 'GREEN', 'YELLOW', 'RED'


##============== SENSOR & ACTUATOR IO FUNCTION ==============##

def weight_isNow():     # Read weight sensor.
    '''read loadcell input'''
    ser.write('weight'.encode('ascii'))
    buffer = ''
    while True:
        temp = ser.read().decode('ascii')
        if temp == '\n':
            break
        else:
            buffer += temp
    weight = 1023 - int(buffer)
    if weight < 0:
        weight = 0
    weight /= 4
    return weight

def btn_recvPhone():    # Check if receive phone button is pushed.
    '''read button input'''
    return gp.input(PIN_RECVPHONE)

def camera_takePhoto(): # From camera, take photo and return the photo.
    with picamera.PiCamera() as camera:
        camera.start_preview()
        time.sleep(5)
        camera.capture('capture.jpg')
        taketime = time.time()
        camera.stop_preview()
    img = Image.open('capture.jpg')
    return img, taketime

def setServoPos(servo, degree):
    if degree > 180:
        degree = 180
    
    duty = SERVO_MIN_DUTY+(degree*(SERVO_MAX_DUTY-SERVO_MIN_DUTY)/180.0)
    servo.ChangeDutyCycle(duty)

door_openSpeed = 0.03
def make_doorLock():    # Check if door is closed, and lock. If door is not closed so failed to lock, return false.
    print('Lock Door...')

    # Close Door
    for i in range(90):
        angle = (180-i)
        '''write angle'''
        setServoPos(servo0, angle)
        time.sleep(door_openSpeed)
    if weight_isNow() <= (3+weight_saved*weight_err):
        # If Sth Strange
        angle = 180
        '''write angle'''
        setServoPos(servo0, angle)
        print('Sth Strange!')
        print('Failed to Lock Door.\n')
        return False
    
    # Lock Locker
    '''Lock Locker'''
    setServoPos(servo1, 90)
    
    print('Successfully Locked Door.\n')
    return True

def make_doorUnlock():  # Unlock Door
    print('Open Door...')

    # Unlock Locker
    '''Unlock Locker'''
    setServoPos(servo1, 0)

    # Open Door
    for i in range(90):
        angle = 90+i
        '''write angle'''
        setServoPos(servo0, angle)
        time.sleep(door_openSpeed)
    
    print('Successfully Opened Door.\n')
    return True

def make_ledlight(tf):
    if tf == True:
        gp.output(PIN_LEDLIGHT, gp.HIGH)
    else:
        gp.output(PIN_LEDLIGHT, gp.LOW)

def make_ledstatus(s):
    if s == 'OFF':
        gp.output(PIN_BLED, gp.LOW)
        gp.output(PIN_GLED, gp.LOW)
        gp.output(PIN_YLED, gp.LOW)
        gp.output(PIN_RLED, gp.LOW)
    elif s == 'BLUE':
        gp.output(PIN_BLED, gp.HIGH)
        gp.output(PIN_GLED, gp.LOW)
        gp.output(PIN_YLED, gp.LOW)
        gp.output(PIN_RLED, gp.LOW)
    elif s == 'GREEN':
        gp.output(PIN_BLED, gp.LOW)
        gp.output(PIN_GLED, gp.HIGH)
        gp.output(PIN_YLED, gp.LOW)
        gp.output(PIN_RLED, gp.LOW)
    elif s == 'YELLOW':
        gp.output(PIN_BLED, gp.LOW)
        gp.output(PIN_GLED, gp.LOW)
        gp.output(PIN_YLED, gp.HIGH)
        gp.output(PIN_RLED, gp.LOW)
    elif s == 'RED':
        gp.output(PIN_BLED, gp.LOW)
        gp.output(PIN_GLED, gp.LOW)
        gp.output(PIN_YLED, gp.LOW)
        gp.output(PIN_RLED, gp.HIGH)



##========================= UTIL FUNCTIONS =========================##

def server_connect():
    print("Check Server Connection.")

    nowtry = 1
    while nowtry <= SERVER_MAXTRY:
        resp = requests.get(SERVER_URL)
        if resp.status_code != 201:
            print("    Server doesn't respond... (", nowtry, "/", SERVER_MAXTRY, ")")
            if nowtry == SERVER_MAXTRY:
                print("Failed to Connect Server. Operating as a Offline Mode.")
                return False
            else:
                time.sleep(5)
            nowtry += 1
        else:
            print("Server Connected!")
            return True

def time_isForUse():
    result = False
    # Online Mode
    if server_isConnected:
        params = {'adminId': admin_id, 'millis': int(time.time())}
        canUse = requests.get(SERVER_URL+'/api/soldier/return/time/valid', params=params)
        if canUse.text == 'true':
            result = True
    # Offline Mode
    else:
        time_now = time.localtime(time.time())
        nt = time_now.tm_hour*60 + time_now.tm_min
        # Weekend
        if time_now.tm_wday == 5 or time_now.tm_wday == 6:
            start_hour = 8
            start_minute = 0
            end_hour = 21
            end_minute = 0
        # Weekday
        else:
            start_hour = 17
            start_minute = 30
            end_hour = 21
            end_minute = 0

        start_time = start_hour*60 + start_minute
        end_time = end_hour*60 + end_minute
        if start_time < nt and nt < end_time:
            result = True
                
    return result

def qr_decrypt(photo, key_vector):  # Decrypt photo
    new_img = copy.deepcopy(photo)
    # new_img = new_img.resize((512,288))

    # Blur
    # new_img = cv2.blur(new_img, (5,5))

    # Generate o.n.basis with key vector
    e1 = np.array([1,0,0])
    e2 = np.array([0,1,0])
    e3 = np.array([0,0,1])

    u1 = np.array(key_vector)
    u1 = u1 / np.linalg.norm(u1)

    u2 = e2 - np.dot(e2, u1) / np.dot(u1, u1) * u1
    u2 = u2 / np.linalg.norm(u2)

    u3 = e3 - np.dot(e3, u1) / np.dot(u1, u1) * u1 - np.dot(e3, u2) / np.dot(u2, u2) * u2
    u3 = u3 / np.linalg.norm(u3)

    key_basis = np.array([u1, u2, u3]).T

    adjust = 220
    for i in range(new_img.size[0]):
        for j in range(new_img.size[1]):
            pixel = np.array(new_img.getpixel((i, j)))
            pixel = (pixel - 127) * adjust / 127
            pixel = np.dot(np.linalg.inv(key_basis), pixel)
            pixel = pixel + np.array((127, 127, 127))
            pixel = pixel.astype(int)
            new_img.putpixel((i,j), (pixel[0], pixel[0], pixel[0]))
    new_img = PIL.ImageOps.invert(new_img)
    new_img.save('decrypted.jpg')

    return new_img

def qr_read(photo): # Detect QR Code from photo, then return serial.
    result = ''
    
    decoded = pyzbar.decode(photo)
    if len(decoded) > 0:
        result = decoded[0].data.decode('utf-8')
    print('    QR Read: ', result)
    if result == '999999999':
        data = {'deviceId': 6, 'totp': 999999999, 'adminId': 1}
        result = json.dumps(data)
    return result

#test_img = Image.open('test.png')
#print(qr_read(qr_decrypt(test_img, [-0.787984  ,  0.55249453,  0.27171862])))
#qr_decrypt(test_img, [-0.787984  ,  0.55249453,  0.27171862]).show()

#tempimg = cv2.imread('img/IMG_0289.jpg')

def sort_points(points):

    points = points.astype(np.float32)
    new_points = np.zeros((4, 2), dtype = "float32")
 
    s = points.sum(axis = 1)
    min_index = np.argmin(s)
    new_points[0] = points[min_index]
    points = np.delete(points, min_index, axis = 0)

    s = points.sum(axis = 1)
    max_index = np.argmax(s)
    new_points[2] = points[max_index]
    points = np.delete(points, max_index, axis = 0)

    if points[0][1] > points[1][1]:
        new_points[1] = points[1]
        new_points[3] = points[0]
    else:
        new_points[1] = points[0]
        new_points[3] = points[1]
 
    return new_points

def transform(img_input, points, size):

    points = sort_points(points)
    topLeft, topRight, bottomRight, bottomLeft = points
 
    maxWidth = size[0]
    maxHeight = size[1]
 
    
    dst = np.array([[0, 0],[maxWidth - 1, 0],
        [maxWidth - 1, maxHeight - 1],[0, maxHeight - 1]],
        dtype = "float32")
 

    H = cv2.getPerspectiveTransform(points, dst)
    img_warped = cv2.warpPerspective(img_input, H, (maxWidth, maxHeight))
 
    return img_warped

def phone_autoCut(photo):
    # Make photo into numpy.ndarray
    print(type(photo))
    if type(photo) == str:
        new_img = cv2.imread(photo, cv2.IMREAD_COLOR)
    elif type(photo) == Image.Image or type(photo) == PIL.JpegImagePlugin.JpegImageFile:
        new_img = np.array(photo)
    elif type(photo) == np.ndarray:
        new_img = copy.deepcopy(photo)
    
    try:
        # Resize & Rotate
        height, width , channel = new_img.shape
        new_width = 540
        new_height = int(height * new_width/width)
        new_img = cv2.resize(new_img, dsize=(new_width, new_height), interpolation=cv2.INTER_AREA)
        new_img = cv2.rotate(new_img, cv2.ROTATE_90_CLOCKWISE)
    except:   
        pass
    if True:
        # Grayscale
        gray_img = cv2.cvtColor(new_img, cv2.COLOR_BGR2GRAY)
        # cv2.imshow('gray', gray_img)
        # cv2.waitKey(0)
        # cv2.destroyAllWindows()

        # Negative & Threshold
        gray_img = cv2.bitwise_not(gray_img)
        ret, gray_img = cv2.threshold(gray_img, 100, 255, cv2.THRESH_BINARY)
        # cv2.imshow('gray', gray_img)
        # cv2.waitKey(0)
        # cv2.destroyAllWindows()

        # Find Contours
        img, cont, hier = cv2.findContours(gray_img, cv2.RETR_EXTERNAL, cv2.CHAIN_APPROX_SIMPLE)
        max_area = 0
        max_index = 0
        for i in range(len(cont)):
            area = cv2.contourArea(cont[i])
            if area > max_area:
                max_area = area
                max_index = i
        max_cont = cont[max_index]
        temp_img = copy.deepcopy(new_img)
        cv2.drawContours(temp_img, [max_cont], -1, (0,255,0), 3)
        # cv2.imshow('gray', temp_img)
        # cv2.waitKey(0)
        # cv2.destroyAllWindows()
        
        # Dilation
        mask = np.zeros(gray_img.shape, np.uint8)
        mask = cv2.drawContours(mask, [max_cont], -1, (255,255,255), 5)
        kernel = np.ones((30,30), np.uint8)
        dilated = cv2.dilate(mask, kernel, iterations=1)
        img, cont, hier = cv2.findContours(dilated, cv2.RETR_EXTERNAL, cv2.CHAIN_APPROX_SIMPLE)
        max_area = 0
        max_index = 0
        for i in range(len(cont)):
            area = cv2.contourArea(cont[i])
            if area > max_area:
                max_area = area
                max_index = i
        max_cont = cont[max_index]
        # cv2.imshow('gray', dilated)
        # cv2.waitKey(0)
        # cv2.destroyAllWindows()

        # Approx
        epsilon = 0.1 * cv2.arcLength(max_cont, True)
        approx = cv2.approxPolyDP(max_cont, epsilon, True)

        # Convex Hull
        hull = cv2.convexHull(approx)
        temp_img = copy.deepcopy(new_img)
        cv2.drawContours(temp_img, [hull], -1, (0,0,255), 3)
        # cv2.imshow('gray', temp_img)
        # cv2.waitKey(0)
        # cv2.destroyAllWindows()

        # Hull Size Calc
        lines = []
        for i in range(len(hull)):
            lines.append(np.linalg.norm(hull[i][0] - hull[(i+1)%len(hull)][0]))
        lines.sort()
        # print(lines)

        # Front View
        points = []
        for p in hull:
            points.append(p[0])
        points = np.array(points)

        img_phone = transform(new_img, points, (int(lines[1]), int(lines[3]*1.2)))
        # cv2.imshow('gray', img_phone)
        # cv2.waitKey(0)
        # cv2.destroyAllWindows()

        return img_phone

    #except Exception as e:
    #    print('Failed to Autocut...')
    #    print(e)
    #    return new_img
temp_img = phone_autoCut('img/IMG_0301.jpg')
cv2.imwrite('autocut.jpg', temp_img)

def img_to_base64(img):
    return base64.b64encode(img)
# print(img_to_base64(temp_img))

def server_returnValid(id_, TOTP, time):
    now = np.floor(time * 1000)
    print('Request Validity Check: deviceId ', id_, ', TOTP: ', TOTP, ', time: ', now)
    params = {'deviceId': id_, 'expectedTOTP': TOTP, 'timeInMillis': now}
    response = requests.post(url=SERVER_URL+'/api/totp/valid', data=json.dumps(params), headers={'Content-Type': 'application/json'}).text
    
    if response == 'false':
        response = False
    else:
        response = True
    return response

# print(server_returnValid(1, 999999999, time.time()))

def server_returnLog(id, returnTime, weight):
    cv2.imwrite('cam.jpeg', phone_autoCut(camera_takePhoto()[0]))
    with open('cam.jpeg', 'rb') as img:
        photo_str = 'data:image/jpeg;base64,'+str(base64.b64encode(img.read()).decode('utf-8'))
    params = {'deviceId': id, 'returnTime': np.floor(returnTime*1000), 'weight': weight, 'photo': photo_str}
    # params = {'photo': photo_str}
    
    result = requests.post(url=SERVER_URL+'/api/log/create', data=json.dumps(params), headers={'Content-Type': 'application/json'})
    return result

# print(server_returnLog(1, time.time(), 100))



##========================= RUN PROGRAM =========================##


# Opening Ceremony
make_ledstatus('OFF')
time.sleep(0.5)
make_ledstatus('BLUE')
time.sleep(0.5)
make_ledstatus('GREEN')
time.sleep(0.5)
make_ledstatus('YELLOW')
time.sleep(0.5)
make_ledstatus('RED')
time.sleep(0.5)
make_ledstatus('OFF')
time.sleep(0.5)

make_ledlight(False)

# Check Server Connection

server_isConnected = server_connect()
print()


# Check Self Status (using pickle)

with open('save.pickle', 'rb') as fr:
    data = pickle.load(fr)
if data['phone_isFull'] == True:
    print('Tray Check: Sth Already Inside.\n')
    phone_isFull = True
    weight_saved = data['weight']
    admin_id = data['adminId']
else:
    print('Tray Check: Nothing Inside.\n')
    phone_isFull = False


print('Start Main Loop.')
while True:
    print('weight: ', weight_isNow(), '/', weight_saved)

    if phone_isFull:    # ANTI-THEFT
        make_ledstatus('BLUE')
        # Check If GetPhone Button is Pushed
        if btn_recvPhone():
            print('Receive Phone Button Pressed!')
            if time_isForUse():
                make_doorUnlock()
                # Change Status
                phone_isFull = False
                weight_saved = 0
                admin_id = 0
                print('    Changed Status.')
                # Save Status
                temp_save = {'phone_isFull': phone_isFull, 'weight': weight_saved, 'adminId': admin_id}
                with open('save.pickle', 'wb') as fw:
                    pickle.dump(temp_save, fw)
                print('    Status Saved.')
                print('    Please Take Out the Phone.')
                make_ledlight(True)
                while True:
                    if weight_isNow() < 5:
                        break
                    time.sleep(1)
                time.sleep(3)
                make_ledlight(False)
            else :
                print('But Not Time for Use!')
                make_ledstatus('YELLOW')
                time.sleep(3)
                make_ledstatus('BLUE')
        

    else:
        make_ledstatus('OFF')
        # Check If Weight Sensor Has Changed
        if abs(weight_saved - weight_isNow()) <= (3+weight_saved * weight_err):
            # Nothing Happend
            pass
        else:
            # Something Entered
            make_ledstatus('GREEN')
            print('Weight Sensor Activated!')
            weight_temp = weight_isNow()
            print('weight: ', weight_temp)

            # 불좀 켜줄래?
            make_ledlight(True)
            
            #   Then Filter Noise Case
            time.sleep(0.5)
            if abs(weight_saved - weight_isNow()) <= (3+weight_saved * weight_err):
                print(' -> was an noise case.')
                make_ledstatus('OFF')
                make_ledlight(False)
                continue
            else:
                print(' -> sth entered in the tray.')
            make_ledstatus('GREEN')
            
            #   Lock Door
            door_maxtry = 3
            door_locked = False
            for i in range(door_maxtry+1):
                if make_doorLock():
                    door_locked = True
                    print('    Door Locked.')
                    break
                else:
                    print('    Door Cannot be Locked!')
            if not door_locked:
                print('Return Canceled: Door Problem!')
                make_ledstatus('YELLOW')
                make_doorUnlock()
                continue
            
            #   Wait for next TOTP, take photo
            print('    Reading QR Code...')
            time.sleep(TOTP_DELAY)
            # qr = qr_read(qr_decrypt(camera_takePhoto(), [1,0,0]))
            qr, return_time = camera_takePhoto()
            qr = qr_read(qr)
            print('    QR: ', qr)
            print('    RT: ', return_time)

            if qr != '':
                # If QR Code Detected, request server phone return
                try:
                    qr = json.loads(qr)
                    print(qr)
                    success = server_returnValid(qr['deviceID'], qr['TOTP'], return_time)
                    print(success)
                except:
                    print('except')
                    success = False
                if success:
                    # If good return case
                    print('    Valid QR Code!')
                    make_ledstatus('BLUE')

                    # Measure weight properly
                    mean_weight = weight_isNow()
                    for i in range(10):
                        mean_weight = mean_weight * i/(1+i) + weight_isNow() /(1+i)
                        time.sleep(0.05)
                    print('    Weight: ', mean_weight)

                    # Change Status
                    phone_isFull = True
                    weight_saved = mean_weight
                    admin_id = qr['adminID']
                    
                    # Save Status
                    temp_save = {'phone_isFull': True, 'weight': weight_saved, 'adminId': admin_id}
                    with open('save.pickle', 'wb') as fw:
                        pickle.dump(temp_save, fw)
                    print('    Status Saved.')

                    # Request server: phone return log
                    server_returnLog(qr['deviceID'], return_time, weight_isNow())
                    print('    Sent Server Return Log.')

                    # Notice User Successful Phone Return
                    print('Return Finished Successfully.')

                    time.sleep(3)

                else:
                    # If bad return case
                    
                    # Alert User
                    print('Return Canceled: Invalid QR Code.')
                    make_ledstatus('YELLOW')
                    make_ledlight(False)
                    
                    # Open Door
                    make_doorUnlock()
                    
                    # Wait Till Phone is Out
                    while weight_isNow() > 5:
                        time.sleep(1)
                    time.sleep(10)

            else:
                # No QR Code
                print('Return Failed: QR Reading Failed.')
                make_ledstatus('YELLOW')
                make_ledlight(False)
                
                # Open Door
                make_doorUnlock()
                
                # Wait Till Phone is Out
                while weight_isNow() > 5:
                    time.sleep(1)
                time.sleep(10)

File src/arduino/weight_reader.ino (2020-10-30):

/*
    Copyright (C) 2020  Pon Johm Naimann

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
    You should have received a copy of the GNU General Public License
    along with this program.  If not, see <https://www.gnu.org/licenses/>.
*/

void setup() {
  Serial.begin(9600);
}

void loop() {

  if(Serial.available()){
    String input = Serial.readString();
    Serial.println(analogRead(A0));
  }
}

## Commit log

2020-10-11 ENH : Public 상수, 함수 및 메인 루프 구현
    Resolves #1
    [main.py]
2020-10-11 ENH : QR코드를 인식하고 그 값을 서버를 통해 검증
    카메라 기능은 임시로 PC 화면 캡쳐로 구현하여 확인하였음.
    Resolves #4
    [main.py]
2020-10-11 ENH : Key Vector 기반 이미지 Decoding 기능 구현
    * qr_decrypt: 이미지와 Key Vector를 인자로 받아 변환된 이미지를
    반환한다.
    Resolves #6
    [main.py]
2020-10-11 ENH : 핸드폰을 찍은 사진에서 핸드폰의 영역을 검출하여 정면 시야로 변환하고 자동 Resize
    반납기 내부 환경을 잘 조성하여야 함.
    * 배경이 되는 바닥 부분을 순백색으로 준비할 것.
    * 적절한 조명을 제공하여 그림자로 인한 인식 오류를 방지할 것.
2020-10-12 BUG : phone_autoCut 함수의 인자, 반환값 통일
    phone_autoCut 함수의 맨 처음에 인자로 들어온 객체의 타입을 확인하여 numpy.ndarray로 변환.
    예외처리 경우의 반환값도 numpy.ndarray로 통일.
    Resolves #10
    [main.py]
2020-10-12 ENH : 이미지를 Base64 포맷으로 인코딩하는 함수 구현
    내장 모듈인 base64 모듈을 사용하여 이미지를 Base64로 인코딩하는 img_to_base64 함수를 구현하였음.
2020-10-12 ENH : save.pickle에 현재 상태 저장
    Resolves #17
    [main.py]
2020-10-13 DOC : license.md 파일 추가
    Resolves #21
2020-10-13 DOC : README.md 파일 추가
    양식만 따와서 복붙함
    Resolves #20
2020-10-13 ENH: 서버에 반납 기록을 전송하는 server_returnLog 함수 구현
    현재 server단에서 임시 구현 상태라서server에 전송하는 POST는
    "photo" : 핸드폰 사진의 base64 인코딩 문자열
    하나로 이루어져 있음.
    다만 원래 방식인 id, 시간, 무게, 사진으로 이루어진 POST를 전송하는 기능
    또한구현하였고, 주석처리 해 둔 상태임.
    추후 서버단이 안정화되면 주석처리만 풀고 사용하면 됨.
2020-10-13 DOC : 반납기 구조 간단히 설계
    SketchUp을 활용하여 반납기의 구조 및 형태를 간단히 설계하였음.
    추후 정확한 치수를 포함한 설계도면을 제작하여야 함.
    Resolves #25
2020-10-13 BUG : 함수의 정의 순서를 조정하고 phone_autoCut을 사용하도록 함.
    server_returnValid, server_returnLog 두 함수를 함수 정의하는 파트의 맨
    뒤로 보냄.
    그리고 반납시 서버에 전송하는 사진에 phone_autoCut을 적용시킴.
    Resolves #27
    [main.py]
2020-10-13 CLN : 서버 URL 변경 및 코드 정리
2020-10-13 CLN : 테스트 파일을 한 폴더로 묶어 정리
    제곧내ㅇㅇ
2020-10-13 DOC : README.md 대강 업데이트
    README.md 대강 정리
2020-10-13 DOC : 로고 이미지 안보이는 오류 수정
    ㅇㅇ
2020-10-13 DOC : 프로'잭'트 -> 프로젝트
    손 '잭'스?
2020-10-13 DOC : 팀 로고 제작
    productPhoto 안에 있음
    Resolves #32
2020-10-14 ENH : 문 잠금, 잠금해제 관리 코드 작성
    실제 GPIO 컨트롤은 내일 라즈베리파이 오면 해볼 예정.
    GPIO컨트롤 부분만 주석처리해두고 나머지 코드는 전부 작성하였음.
    또한 원래 께획은 반납기 자체의 문을 서보모터로 제어하여 열고닫을
    생각이었으나, 설계상의 변화로 스마트폰을 덮는 덮개를 제어하는 것으로
    변경됨. 이는 구조적인 문제일 뿐 코드 구조에 변화는 없음.
    * make_doorLock() : 1초에 걸쳐 문을 닫다가 무게 변화가 감지되면 문
    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
2020-10-15 CLN : 개발 환경을 윈도우PC에서 라즈베리파이로 이전, 코드 수정
    라즈베리파이에 필요 라이브러리 설치 등 개발환경 구축
    기존 코드에서 ImageGrab라이브러리 제외
    Resolves 35
    [main.py]
2020-10-15 ENH : 지금 시간이 핸드폰 사용가능 시간인지 서버로부터 확인받는 기능 구현
    time_isForUse 함수에서 requests모듈을 사용하여 서버에게 요청함.
    응답은 true, false 문자열 중 하나로 받으며 함수는 각 경우에 따라 bool 형의 값을
    반환함.
    Resolves #12
    [main.py]
2020-10-16 DOC : 회로도 circuit.jpg 첨부
    ㅈㄱㄴ
    Resolves #41
2020-10-16 ENH : QR코드에서 adminId를 추가로 읽고 time_isForUse에서도 활용
    QR코드에서 읽는 정보에서 adminId를 추가하였음.
    time_isForUse에서 서버에 보내는 요청에 adminId를 추가함.
    save.pickle에 저장할 때에도 admin_id 값을 저장함.
    추가적으로, server_returnValid에서도 adminId를 검증받을 수 있으면
    좋겠음.
    Resolves #39
    [main.py]
2020-10-17 ENH : 반납기 회로 작성 및 라즈베리파이 GPIO 설정
    브레드보드와 점퍼 케이블을 활용하여 회로를 작성하고 라즈베리파이 GPIO핀과 연결시켰음.
    추가적으로 라즈베리파이 환경에서 돌아가도록 코드 일부 수정함.
    * cv2.VideoCapture(0) -> picamera.PiCamera()
    * cont, hier = cv2.findContour(~) -> img, cont, hier = cv2.findContour(~)
    Resolves #44
    [main.py]
2020-10-17 ENH : 압력센서 사용 가능!
    아두이노 나노를 거쳐서 압력센서의 값을 읽어오는 기능을 구현하였음.
    다만 압력센서의 값은 0~1023 범위의 값으로 들어오는데, 이를 조정(Calibration)하여 g(그람) 단위의 실제 무게로 변환하는 것은 계산이 필요함.
    그 계산은... 곧 하겠음...
    Resolves #47
    [main.py]
2020-10-17 ENH : 서보모터를 제어하여 문 열고 닫기
    서보모터로 문을 열고닫을 수 있다.
    핸드폰이 올려지면 잠시 후 커버가 닫힌다.
    커버가 닫힌 상태에서 QR코드를 인식한다.
    커버가 닫힌 상태인데 무게가 0이거나, QR코드 인식에 실패하는 등 반납이 제대로 이루어지지 않은 경우,
    커버가 자동으로 다시 열린다.
    그리고 사용자가 다시 핸드폰을 가져갈때까지 대기한다.
    사용자가 핸드폰을 가져가면, 다시 처음 상태로 돌아와 새로운 핸드폰이 들어오기까지 기다린다.
    Resolves #49
    [main.py]
2020-10-17 TST : 테스트용 마스터 TOTP 설정
    TOTP가 999999999 인 경우(9가 9개), server_returnValid함수는 무조건 'true'를 반환한다.
    또한 test파일에 QR코드 색상암호화/색상복호화 코드 추가하였음.
    각각 qr_gen.py, qr_decoder.py 임.
    Resolves #51
    [main.py]
2020-10-17 DOC : 반납기 회로도 업데이트
    이슈 #53에서 말한 내용 추가함.
    Resolves #53
    [main.py]
2020-10-18 ENH : 상태표시 LED 점등
    상태에 맞게 LED등이 들어오도록 함.
    그리고 조명용 LED도 제어하도록 함.
    Resolves #55
    [main.py]
2020-10-18 CLN : 반납기 콘솔 출력 수정
    QR코드 읽고 그 값 출력하도록 함.
    아 몇개 더 수정해야지
    [main.py]
2020-10-18 CLN : 반납기 콘솔 출력 수정
    서버에 요청할때도 deviceId, TOTP, 시간 출력함.
    Resolves #57
    [main.py]
2020-10-18 TST : 테스트용 마스터 QR코드 개선
    개선 완료.
    실물 반납기로 돌려보니 반납/불출 모두 매우 잘 작동함!
    Resolves #59
    [main.py]
2020-10-18 BUG : 핸드폰 불출시 보조조명이 꺼지지 않는 버그 수정
    핸드폰을 가져가면 잠시 후 꺼지도록 하였음.
    Resolves #61
    [main.py]
2020-10-18 ENH : 반납기 무게센서 Calibration
    4로 나누면 적당히 맞음.
    Resolves #63
    [main.py]
2020-10-21 DOC : 흰색배경 팀 로고 제작
    Resolves #65
    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
2020-10-25 DOC : 반납기 회로도 LED, 스위치 관련 부분 수정
    LED 회로도에 저항을 추가하였고 실제로도 회로를 작성함.
    KW-10 스위치는 사용하지 않을 예정임.
    Resolves #67
2020-10-25 BUG : 상태표시 LED 제어 코드 정상화 및 App에서 받은 QR코드 JSON화
    LED 제어 기능을 고쳤다.
    그리고 App에서 QR코드에 담는 JSON의 인자를 내가 쓴거랑 좀 다르게 써서
    그것도 고쳤다.
    Resolves #69
    [main.py]
2020-10-25 BUG : APP에서 읽은 QR코드 잘 해독하기
    완료!
    Resolves #71
    [main.py]
2020-10-25 BUG : TOTP 검증 관련 코드 수정, QR코드 인식 시간 기록 시점 조정
    TOTP 검증 관련된 조건문을 수정함.
    추가적으로 TOTP_DELAY의 존재 때문에 QR코드를 인식한 시간의 기록이 섬세하게 이루어져야 했는데,
    섬세하기는 커녕 제멋대로 되어있었다.
    그래서 camera_takePhoto 함수에서 사진을 찍는 순간의 시간도 return 하도록 하였음.
    Resolves #72
    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
    [main.py]
2020-10-28 DOC : 회로도에서 서보모터를 하나만 남김
    문 제어에 서보모터 하나면 거뜬!
    Resolves #75
2020-10-28 DOC : 반납기 3D 모델링 및 가이드 추가
    하는김에 폴더들도 조금 정리함.
    Resolves #77
    [Receiver - Part 1.stl, Receiver - Part 2.stl, Receiver - Part 3.stl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]
2020-10-29 ENH : 아두이노 전용 소스코드 업로드 및 폴더 정리
    arduino 폴더를 만들고 아두이노 코드를 업로드함.
    또한 쓸데없는 파일을 다 지우고 raspi폴더에 필요한 파일만 첨부함.
    Resolves #74
    [main.py]
2020-10-29 CLN : 시리얼 통신 포트 관련 변수 SERIAL_PORT 추가
    이 변수를 조정하여 시리얼 통신에 사용되는 포트를 설정할 수 있다.
    Resolves #80
    [main.py]
2020-10-29 DOC : 시연영상 링크 첨부
    시연영상 동영상 자체를 업로드하려 했으나, 용량이 100MB이상이라 업로드가
    불가능함.
    유투브에 올리고 링크를 텍스트파일에 첨부하였음.
    Resolves #82
2020-10-29 커밋 잘못해서 이미지파일 다수 날려먹었음
    다시 복구함.
    ㅋㅋ...ㅎㅎ;;;ㅈㅅ!!!
2020-10-30 CLN : 리포지토리 폴터, 파일 정리
    소스코드 관련은 src, 문서 관련은 doc으로 묶었다.
    그리고 프로그램 실행시에 부가적으로 생성되는 파일들도 전부 지웠다.
    Resolves #87
    [Receiver - Part 1.stl, Receiver - Part 2.stl, Receiver - Part 3.stl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]
2020-10-30 DOC : 발표 PPT 업로드
    Resolves #89
2020-10-30 DOC : 발표PPT 내림
    아직 다 만들지도 않은걸 올리구그래
2020-10-30 DOC : MAINTAINERS.md 추가
2020-10-31 DOC : PPT파일 정리
2020-11-01 ENH : README.md 파일 한글, 영문 추가
    * README_KR.md : 한글
    * README_EN.md : 영문
2020-11-01 BUG : README_EN.md 파일 링크 경로 오류 수정

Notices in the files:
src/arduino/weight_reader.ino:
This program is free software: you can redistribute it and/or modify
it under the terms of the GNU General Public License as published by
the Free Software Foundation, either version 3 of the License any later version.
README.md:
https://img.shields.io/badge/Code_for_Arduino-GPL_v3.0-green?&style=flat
